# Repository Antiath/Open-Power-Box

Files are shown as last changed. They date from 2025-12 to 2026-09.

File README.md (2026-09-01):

# 🔭 Open Power Box: Heavy Duty Power Distribution System for Astrophotography Equipment
**Open Power Box** is a complete, open-source hardware and software project designed to build a robust power distribution box specifically for an **observatory-class amateur astronomy setup**. While many similar projects exist, they often target compact, portable systems; this project is built for greater capabilities. The hardware side of the project is designed following the specifications detailled below but the firmware, though preconfigured for this specific hardware, has been written to allow scalability to an arbitrary number of outputs so that one could use it as-is for his custom version of the project, with minimal adjustments to the firmware. 

**LICENSING** : The entire project is **completely open source**. The hardware files and documentation fall under the **Licence CC BY-SA 4.0**, while the drivers and the firmware are licensed under **GNU Lesser General Public License version 3 (LGPLv3)** 

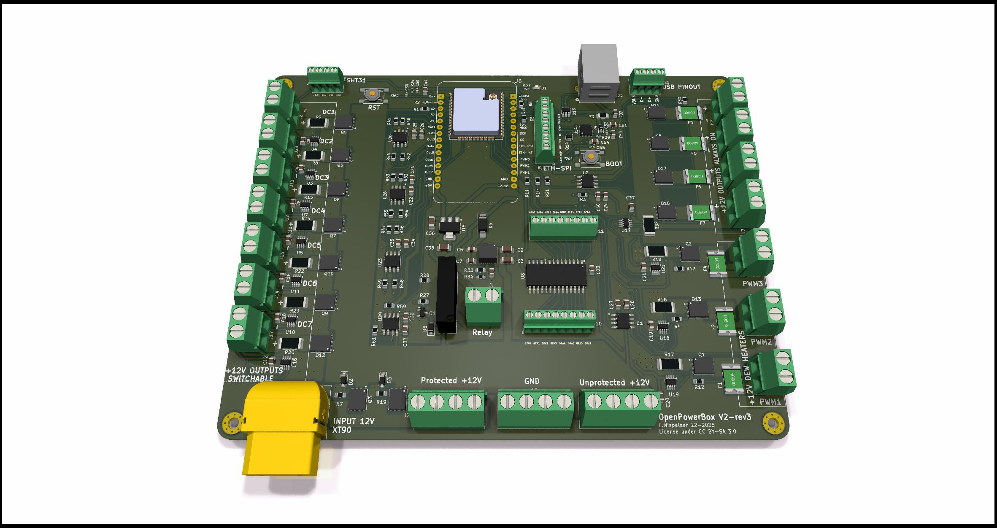
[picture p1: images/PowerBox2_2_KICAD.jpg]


## ✨ Key Features

### Power and Output Specifications
* **Input:** 12V (nominal, unregulated) DC with a **20A limit**. The polarity protection circuit can handel up to 20V without damaging it but we really recommand to stay around 12V as there is no voltage regulation on the output.
* **Switched DC Outputs:** 7 individual ON/OFF DC switches, rated at **12V/5A each**.
* **Dew Heater Outputs:** 3 outputs with low-frequency PWM control, rated at **12V/2A each**.
* **Automatic Dew Heater Control** Using a SHT31 sensor on the i2c bus, the device can regulate the power of a heater band.
* **12V Rail:** A single rail of 4 DC outputs for devices that don't need individual control, limited to **12V/5A for the whole rail**. Useful for things that stay on all the time for exemple.
* **Switchable Relay:** A relay useful for controlling a device with specific voltage requirements, max **30V-5A**.
* **Switchable USB Hub (Optional):** A 7-port switchable USB2 hub (on a second PCB). This allows for remote USB connection reset if a peripheral malfunctions, but a simple off-the-shelf hub can also be used if this feature is not needed.

### Protection and Customization
* **Configurable Software Fuses:** Most switches have a dedicated current sensor to monitor current draw and shut down the switch if a configurable limit is exceeded. These limits are stored in the EEPROM and can be modified in the clients.
* **Global Limits:** Three global current limits are also in place, one for the 7 DC switches together, one for the dew heaters together, and one for the total input current. And the total limit of 20A for the whole box (excluding the relay). These limits will shut down parts of the device in a sequence of priorities.
* **Reverse Polarity Protection:** The XT90 input connector is folowed by a reverse polarity protection circuit.
* **Reversible Logic:** Switch logic can be swapped to correct issues where the client-side toggle is reversed (ON/OFF issue).

### Connectivity and Communication
The device supports multiple communication methods, allowing a choice of OS and connection type (USB or WiFi).

| Connection Type | Operating System | Client Interface | Notes |
| :--- | :--- | :--- | :--- |
| **USB/Serial** | Windows | ASCOM Driver | The ASCOM driver provides its own minimised UI, similar to GSS or EQMOD. |
| **USB/Serial** | Linux | Indi Driver | Use the dedicated Indi driver (In development). |
| **WiFi** | Windows | Alpaca Server | Provides similar functionnality to the ASCOM USB driver but no driver installation needed if your client supports Alpaca; it finds the device on the network automatically.|
| **WiFi** | Any OS | HTTP Browser Interface | Accessible at the device's IP address on port 4040. Meant for quick device configuration only (like a router's configuration page).  |

---

## 🛠️ Project Components

The complete project includes everything you need to build and run your own power box:
* **Hardware:** Schematics, gerber files, and a Bill of Materials (BOM) list for PCB creation.
* **Enclosure:** STL files for 3D printing an enclosure.
* **Software:**
    * **Firmware:** Includes base code, serial communication, an HTTP server for a browser interface, and an ASCOM/Alpaca server.
    * **Drivers:** ASCOM Driver and Indi Driver.
 
## 🛠️ Completed build illustrations

### Standard version

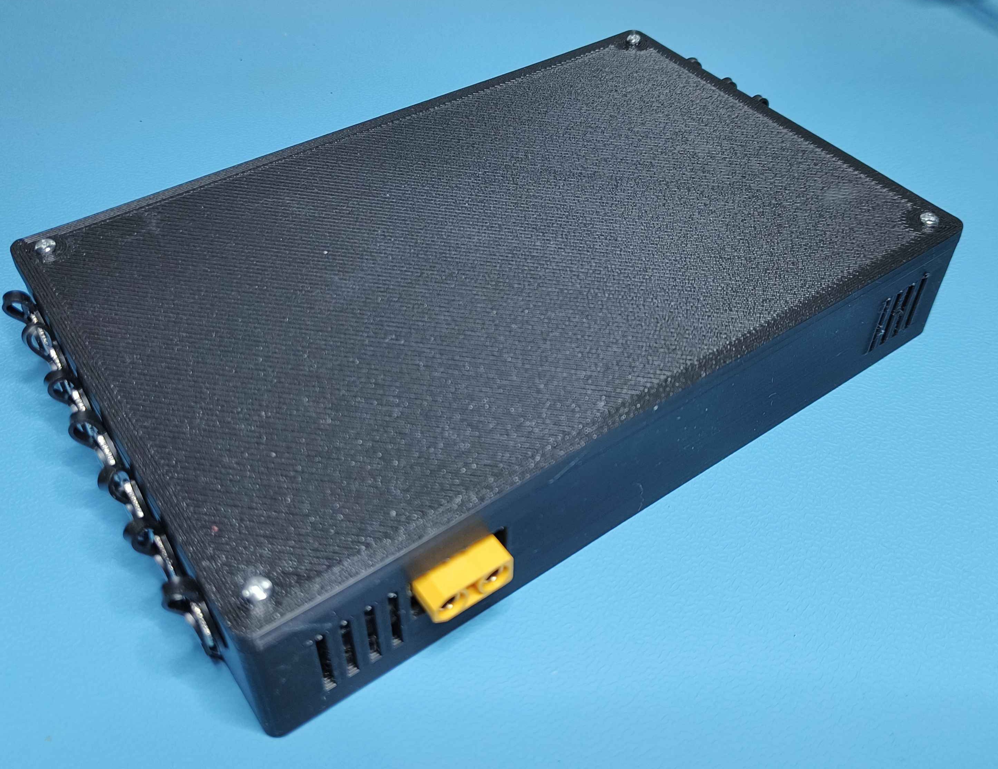
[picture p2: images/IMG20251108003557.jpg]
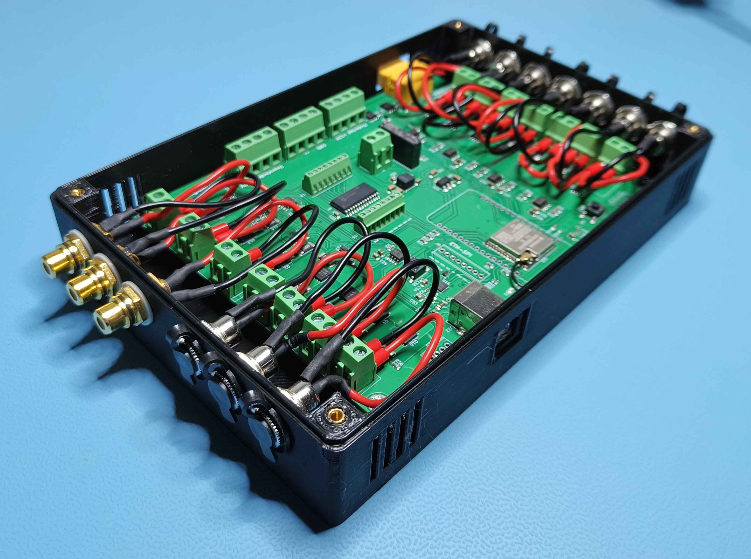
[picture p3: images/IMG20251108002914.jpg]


### USB HUB version

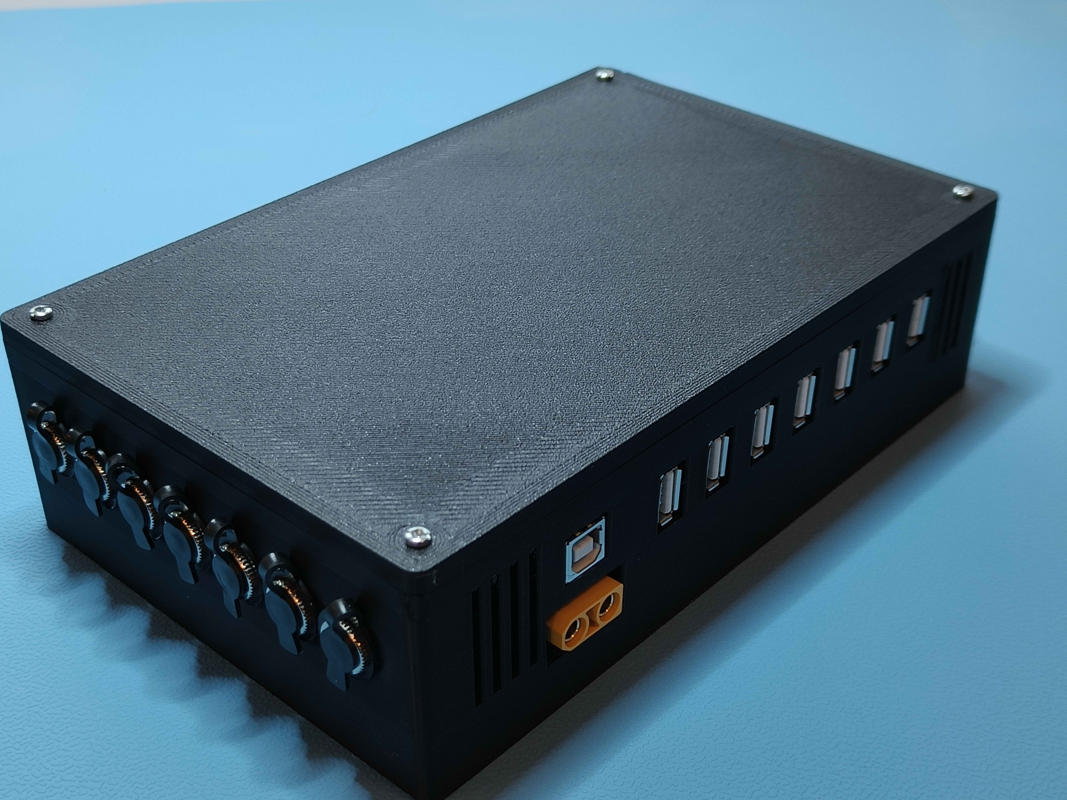
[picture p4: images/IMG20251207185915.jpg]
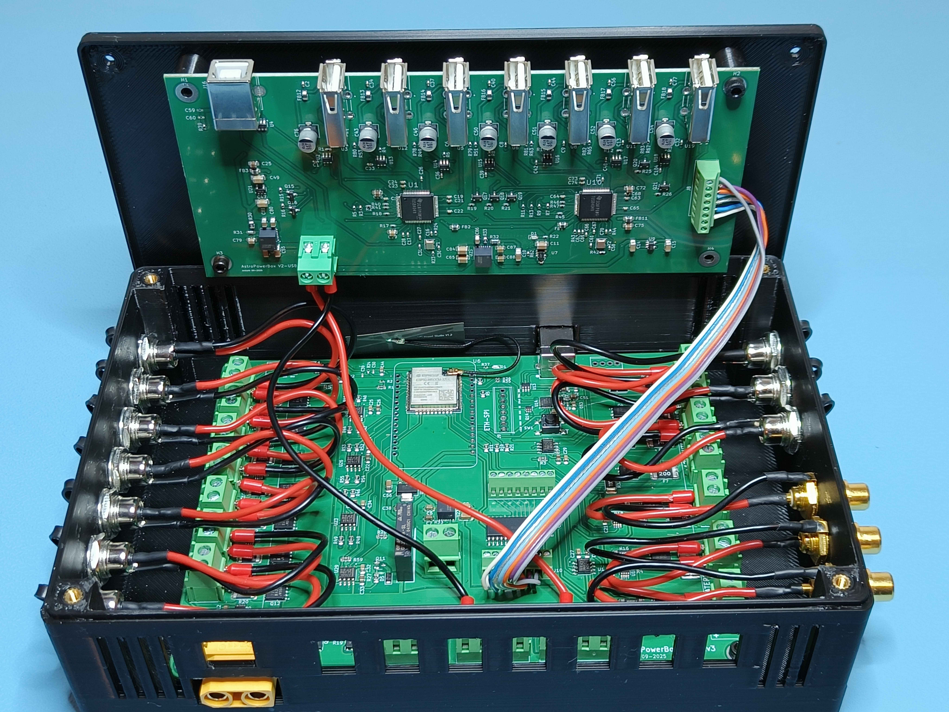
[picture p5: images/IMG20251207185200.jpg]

---

## 🚀 Getting Started

### 🔌 Flashing the firmware

Tho ways of flashing the firmware are provided. Choose the one that is the most convenient for you.

#### PlatformIO

Right now the project is configured via Visual Studio Code and PlatformIO. Open Visual studio Code, clone this repositery inside and set your workplace in the Firmware-platformIO subfolder of the repo. It should configure and download everything automatically, including the required libraries. Once everything is finished,  connect the box via USB, select the right USB Port and flash the firmware. Normally you shouldn't have anything more to do but if for some reason  the flash fails when attempting to upload,  press the BOOT button on the pcb, keep pressing and reflash again. Wait for it to finish. 

#### Arduino IDE

For the ArduinoIDE route, there is a little bit more work to be done. Download this repository somewhere. In the Firmware-ArduinoIDE subfolder, open the OpenPowerBox.ino sketch in the Arduino IDE (v2 at least). If uou dont have already done so, go into the board manager et install the dependencies for the esp32 from Espressif Systems ( not by Arduino !!!). Version 3.3.7 is known to work. Then in the library manager, install the following libraries ( I specify the version each time because more recent version may, or may not work) : 
* Adafruit BusIO (v1.17.4) by Adafruit
* Adafruit MCP23017 Arduino Library (v2.3.2) by Adafruit
* Adafruit SHT31 Library (v2.2.2) by Adafruit
* Arduinojson (v7.4.2) by Benoit Blanchon
* SerialCommand Advanced (v1.0.0) by shyd
* WebSockets (v2.7.2) by Markus Sattler
* INA219 (v0.4.2) by Rob Tillaart

Once everything is installed properly, go into Tools and select the esp32 board named " ESP32 Dev Module", select the right USB port. Also, it is not mandatory but it is still a good idea to change the partitionning of the esp32 to free up some space for the programm ( by default it would occupy 85% of the available program memory) so in Tools > Partition Scheme, select Huge APP ( 3MB No OTA, 1MB SPIFF).
Then you can try to compile. Ignore the yellow warnings, if there are no errors, flash the firmware.

#### Firmware Configuration

The default configuration of the firmware is for a power box with 7 DC outputs, 3 PWM Dew Heaters, 1 DC bank, 1 relay, 0 USB ports and Automatic Dew heating activated.
If you need any other configuration, you can edit the following lines in config.h. But be aware than any configuration other than default will make the webpage unusable.

```
const short DCOutput_Num = 7;  // Number of stable 12V outputs. 
const short PWMOutput_Num = 3; // Number of PWM controlled outputs.
const short RelayOutput_Num = 1; // Number of relay outputs.
const short OnOutput_Num = 1; // Number of always ON 12V switches (the whole bank of connectors is controlled by the same switch)
const short USBOutput_Num = 0; // Number of USB controlled outputs. Maximum is 7.
const bool Ren =true; // Falg to enable/disable the automatic power control of dew heaters. This only affects the firmware and display of the sensor, you will still have to activate automatic control in the driver.
```
For example, if you want the USB Hub version of the project, set USBOutput_Num to 7 instead of 0.
If you don't need Automatic control of the dew heaters ( meaning of you don't have a SHT31 sensor hooked up), Set Ren to false instead of true.

For the more advanced users that want to design their own pcb with an entirely different configuration, there are a few things to consider.
The main switches are DCOutput_Num and PWMOutput_Num. The DC Bank with ganged connectors behind a single transistor is specified by OnOutput_Num, and the relay by RelayOutput_Num.
If you need a different number of individual DC/PWM or USB ports, you can change DCOutput_Num, PWMOutput_Num or USBOutput_Num. Be aware that the pcb is configured for these and also that the esp32 has a limited amount of I/O. 
If you need less outputs, it's pretty easy. Just read below  in config.h to know wich pins are used by the firmware for each type of output.
If you need more outputs...(wich you really shouldn't it's already a big boy) it's possible but you would have to change the arrays that store the pin adresses of each output type and add the pins you need. 
And lastly, there can only be a maximum number of 1 for the relay and the DC Bank. The firmware doesn't allow currently for more.

To get your Open Power Box communicating with your host PC, you will need to install the appropriate drivers.

### 🔌 Windows Setup (USB/Serial)

If you are using **Windows** and connecting via **USB/Serial**, you must install the **ASCOM driver**:

1.  **Install the ASCOM Driver:** Download and install the dedicated ASCOM Driver for this project.
2.  **Connect the Device:** Connect the power box to your Windows PC via the USB/Serial interface.
3.  **Client Interface:** The driver provides a limited user interface in your preferred client (like **NINA**) with control for all the switches and display of the main measurements.
7.  **Driver UI:** When you open the COM port, in addition to the controls available in the client ,the driver will also automatically launch its own **User Interface**, minimized by default, functioning similarly to tools like GSS or EQMOD. This last UI provides the full functionnality of the device.
   
### 💻 Linux Setup (USB/Serial)

If you are using **Linux** and connecting via **USB/Serial**, you can use the provided INDI driver. It should be available through the last release of INDI but in case it isn't, you can compile from source.

1. Make sure you have a stable installation of **INDI** and **cmake**.
2. If this is not already done,  make also sure you have the right dependencies to build indi projects:
```
sudo apt install build-essential devscripts debhelper fakeroot cdbs software-properties-common cmake
sudo add-apt-repository ppa:mutlaqja/ppa
sudo apt install libindi-dev libnova-dev libz-dev libgsl-dev
```
3. Download/clone this repository, open a terminal into INDI Driver, make a new build folder and cd into it.
```
mkdir build
cd build
```
5. Inside the build folder, execute the following commands
```
cmake -DCMAKE_INSTALL_PREFIX=/usr -DCMAKE_BUILD_TYPE=Debug ../
```
You should now see the config.h and indi_opbdriver.xml files.
Stay in the Build folder and build the executable
```
make
```
and install the driver now with
```
sudo make install
```
6. In Ekos, the driver will be located in the Power category under the Generic Manufacturer and **named Open Power Box**
7. When loading the driver, you will need to paste the usb id of the device. You can find it in a terminal with
```
ls /dev/serial/by-id
```
or
```
ls -l /dev/serial/by-id
```

### 🌐 WiFi Setup

#### Setting up the WiFi credentials in the device

##### Via the USB Driver
After flashing the device with the firmware, there will be no SSID or password stored. To do that, you can use the ASCOM USB Driver. After installing it, lauch you client of choice and select the ascom driver, then your COM Port in the settings and connect. The auxiliary UI will appear. Click on the Parameter tab and below you can fill the fields for the SSID and the password. Click on the Restart button to reset the device. After a few seconds, if the device managed to connect,  the IP address displayed in the UI will be updated. The device is now ready to be used via the local network.   

##### Via Editing the Frimware
If you really don't want or can't install the usb driver, you can still store the WiFi credentials in the code before flashing it. 
Open main.cpp, find the following lines:
```
   //ssid1=""; 
   //pwd1="";
```
remove the // on both linesand add your SSID and password in the between the "", like for exemple : 
```
   ssid1="ssidwifi"; 
   pwd1="passwifi";
```
and finally Flash the device.
To get the IP address, open a Serial connection on the COM Port and push the reset button on the pcb. The IP address will be displayed during boot.
We recommand that you go into your router to reserve that IP address for the MAC address of the device.

####  Alpaca
Alpaca is a network version of the ASCOM API. It provides tools to connect to network capable devices and communicate with them in the same way you normally do with a normal USB ASCOM driver. The main difference for the user is that Alpaca only requires that you have an up to date version of ASCOM installed. It does not however requires you to any extra driver for your devices as long as the device can connect to your local network. In you preferred client, say Nina, you would go to your equpment setup page, in the switch section you would open the list of devices and OpenPowerBox should appear by itself if it is already connected to the local network. Sometimes it may take a few trys to get it to appear in the list. Select it, connect and voilà. You have basic access to the device. 

#### Browser
If you know the IP adress of the device and it is connected to the local network, you can open a page at http://ip_adress:4040/. This UI gives you access to almost all the features of the power box appart from automation. In particular, you can read every sensor available wich allows you to debug issues more easily in case of problems with a device. It also allows you to change configuration like the current limits of the software fuses, the logic polarity of the switches, tha names seen by ASCOM and wifi credentials. If the IP adress is unknown, you can get it through the USB interface.  See instructions above.

---

## 🏭 Manufacturing and Assembly Notes

### Choose your fighter : USB Hub or no USB Hub

The project proposes twho versions. The base project only has power switches ( dc and pwm) while the second version add an extra usb hub. This last one requires a second pcb dedicated to the HUB. This has been done to minimize manufacturing costs. The USB hub requires a 4 layer pcb while the power board needs only a 2 layer board. Putting everything on a single 4 layer pcb may force us to make a large and costly board. 

### Printed Circuit Board (PCB) Fabrication
* The main board is a **2-layer board** and should preferably be manufactured with a **2 oz copper thickness** to maximize the amount of copper and minimize voltage drop across the board.
* The USB hub board is a **4-layer board** and can be manufactured with a **normal 1 oz copper thickness on surface layers**. With JLC, specify the JLC04161H-3313 stackup.
  
| Layer | Material Type | Thickness |
| :---: | :---: | :---: |
| Top Layer | Copper | 0.035mm | 
| Prepreg | 3313*1 | 0.09940mm | 
| Inner Layer L2 | Copper | 0.0152mm | 
| Core | Core | 1.265mm | 
| Inner Layer L3 | Copper | 0.0152mm | 
| Prepreg | 3313*1 | 0.09940mm | 
| Bottom Layer  | Copper | 0.035mm | 

The choice of stackup affects the performance of the USB traces on the pcb or, more specificaly this stackup allows us to use really fine traces, wich simplifies the layout phase of the pcb. If you use our gerbers to make your own board, this is the stackup to use. If you choose a different stackup, you will need to re-engineer the differential pairs and redo the layout. This configuaration has been tested and achieves usb transfert speeds up to the theoritical maximum of HIGH SPEED USB2 ( 480 Mbit/s).

* Prototypes were manufactured using **JLC PCB**. If you choose the same manufacturer and encounter out-of-stock parts not easily replaced by an equivalent, you can request that JLC source those specific parts on the global market for use during manufacturing.

### Wiring
* If you are using the provided **3D printable case**, the terminal blocks on the PCB should be oriented **inward** to facilitate easier wiring to the external connectors.
* The connectors you will choose to use need to be rated for the currents you want. Typycal 12v barrel jacks and RCA jacks are not generally made to support large currents so you should be careful when selecting them. The ones used for the building of the test units were found on Amazon and may not be available anymore when you read this. iF you choose other connectors and want to use our 3dprinted case, make sure to correct the hole diamater if necessary.
* The XT90 innput connector we use accepts a gauge of 10 AWG wich should be suitable for 20-30A over 1 or 2m. Flexible multistranded wire should be used here in order to avoid resistance when moving the telescope around as the powerbox would be typically put on top of the setup and its power cable would laying down to you power supply.
* Always size the other cables appropriatly. If you expect to use the full 5A of an output, not only the gauge should be checked but also every intermediary connector, if possible, as they are very likely to not make good enough contact for this kind of stress.
* Terminate your internal wires with ferrules when connecting to a terminal block.
* If you need the SHT31 sensor for the automatic Dew heater deature, there is a row of of 4 holes in a corner of the pcb named SHT31. Solder a 4 slots 2.54mm terminal block or just solder your wires directly. The silkscreen indicates wich pad does what.
* The switching of the usb ports of the hub are handled by the I/O port extender (MCP23017) of the main board. Wiring between the two boards:
  
| Main board | USB Hub board |
| :---: | :---: |
| Connector J10 | Connector J8 | 
| GPA0 | USB-S1 |
| GPA1 | USB-S2 |
| GPA2 | USB-S3 |
| GPA3 | USB-S4 |
| GPA4 | USB-S5 |
| GPA5 | USB-S6 |
| GPA6 | USB-S7 |
  
### Extra component sourcing (if still available at the time of reading):
   * 5.5mm x 2.1mm female barrel jacks from manufacturer RUNCCI-YUN: https://www.amazon.fr/dp/B09TVDDWN2?ref=ppx_yo2ov_dt_b_fed_asin_title
   * RCA female jacks from RUNCCI-YUN: https://www.amazon.fr/dp/B09TPL4TV5?ref=ppx_yo2ov_dt_b_fed_asin_title
   * XT90 connector https://www.amazon.fr/dp/B0CF85B2LY?ref=ppx_yo2ov_dt_b_fed_asin_title&th=1
   * Suitable power supply : Mean well LRS-350-12 wich is a 350W PSU ( or the LRS-450-12 if you can afford it) https://www.meanwell.com/webapp/product/search.aspx?prod=LRS-350 

---

## ⚙️ ASCOM Switch Class Overview

The power box is designed around the **ASCOM Switch class**, which is tailored for peripherals like power boxes and handles On/Off switches, Dew Heaters, and sensors.

In the ASCOM world, these entities are all referred to as a **"switch"**:

* **ON/OFF Switches:** Self-explanatory.
* **Dew Heaters:** Referred to as "**analog**" switches with an infinite range of values instead of just two.
* **Sensors:** Considered "**read-only**" switches.

Clients determine the switch type by querying the `CanWrite`, `Min`, `Max` and `Step` properties. The state of all switches is stored in a large array, with an index defining the order they are read by the client.

### Example Switch Array Structure

| Index | Switch Name | Can Write | Min-Max | Step |
| :---: | :---: | :---: | :---: | :---: |
| 0 | dc1 | Yes | 0-1 | 1 |
| 1 | dc2 | Yes | 0-1 | 1 |
| 2 | pwm | Yes | 0-100 | 10 |
| 3 | sensor | No | - | - |

### Full Switch array

Base Version:

| Switch | DC1 | DC2 | DC3 | DC4 | DC5 | DC6 | DC7 | PWM1 | PWM2 | PWM3 | Ren1 | Ren2 | Ren3 | DC Rail | Relay | Input V | Total A | Total A DC | Total A PWM | DC1_V | DC1_A | DC2_V | DC2_A | DC3_V | DC3_A | DC4_V | DC4_A | DC5_V | DC5_A | DC6_V | DC6_A | DC7_V | DC7_A | PWM1_V | PWM1_A | PWM2_V | PWM2_A | PWM3_V | PWM3_A | DC Rail_V | DC Rail_A | Temp | Hum | Dew_point |
|---|---|---|---|---|---|---|---|---|---|---|---|---|---|---|---|---|---|---|---|---|---|---|---|---|---|---|---|---|---|---|---|---|---|---|---|---|---|---|---|---|---|---|---|---|
| index | 0 | 1 | 2 | 3 | 4 | 5 | 6 | 7 | 8 | 9 | 10 | 11 | 12 | 13 | 14 | 15 | 16 | 17 | 18 | 19 | 20 | 21 | 22 | 23 | 24 | 25 | 26 | 27 | 28 | 29 | 30 | 31 | 32 | 33 | 34 | 35 | 36 | 37 | 38 | 39 | 40 | 41 | 42 | 43 |

USB HUB Version:

| Switch | DC1 | DC2 | DC3 | DC4 | DC5 | DC6 | DC7 | PWM1 | PWM2 | PWM3 | Ren1 | Ren2 | Ren3 | DC Rail | Relay | USB1 | USB2 | USB3 | USB4 | USB5 | USB6 | USB7 | Input V | Total A | Total A DC | Total A PWM | DC1_V | DC1_A | DC2_V | DC2_A | DC3_V | DC3_A | DC4_V | DC4_A | DC5_V | DC5_A | DC6_V | DC6_A | DC7_V | DC7_A | PWM1_V | PWM1_A | PWM2_V | PWM2_A | PWM3_V | PWM3_A | DC Rail_V | DC Rail_A | Temp | Hum | Dew_point |
|---|---|---|---|---|---|---|---|---|---|---|---|---|---|---|---|---|---|---|---|---|---|---|---|---|---|---|---|---|---|---|---|---|---|---|---|---|---|---|---|---|---|---|---|---|---|---|---|---|---|---|---|
| index | 0 | 1 | 2 | 3 | 4 | 5 | 6 | 7 | 8 | 9 | 10 | 11 | 12 | 13 | 14 | 15 | 16 | 17 | 18 | 19 | 20 | 21 | 22 | 23 | 24 | 25 | 26 | 27 | 28 | 29 | 30 | 31 | 32 | 33 | 34 | 35 | 36 | 37 | 38 | 39 | 40 | 41 | 42 | 43 | 44 | 45 | 46 | 47 | 48 | 49 | 50 |

---

## 💬 Serial Communication Protocol
If you choose to use USB to interact with the device, the firmware communicates via serial commands over the COM port. While the webserver is regularly updated, there is no data sent automatically through the serial port, the driver has to poll the device. This means that, for now, the general behavior of the COM port is synchronous.
Each command sent to the device will trigger a response even if no data is necesseraily expected back. For example, if you send the command to change the sate of a switch, the device will execute the command and then send the changed state back as an answer to acknowlege the action.  Also, the formatting of the commands sent to the device is different than the formatting of the reponse. This is intentionnal and allows for easier debugging when sniffing the com port. 

### Command Format (from Host to Device)

Commands use a simple letter and one or two parameters:

* **To Get a Value:** `# <command> <index>`
    * *Example (Get value of the first DC switch - index 0):* `# G 0`
* **To Set a Value:** `# <command> <index> <value>`
    * *Example (Set PWM index 2 to 55):* `# S 2 55`

* The response starts with `#`.
* A space separates the command letter from the index and the index from the value ( if one is required).
* If no index is needed, `0` is included by default.
* No character to terminate other than a newline and carriage return.

### Response Format

Every command  from the client triggers a response:

* **Responding to a Get command:** `#<command><index>:<value>;`
    * *Example (Get value of the first DC switch - index 0, the value is 1):* `#G0:1;`

* The response starts with `#` and is terminated with `;` (plus newline and carriage return).
* A `:` character separates the index from the value.
* No spaces are included.

### ASCOM Compliant Commands

| Method | Command | Response Format | Type [Range] | Description |
| :--- | :--- | :--- | :--- | :--- |
| **Get switch value** | `# G <index>` | `#G<index>:<value>;` | Dc: boo[0-1], PWM: int [0-100], Sensor: float | Get the current state/value of a switch |
| **Set switch value** | `# S <index> <value>` | `#G<index>:<value>;` | Dc: boo[0-1], PWM: int [0-100] | Set the state/value of a switch |
| **Can Write** | `# W <index>` | `#W<index>:<value>;` | boo[0-1] | Tells if the switch is writable or not |
| **Maximum** | `# M <index>` | `#M<index>:<value>;` | Dc: int[1], PWM: int [100] | Gives the maximum writable value |
| **Minimum** | `# m <index>` | `#m<index>:<value>;` | Dc: int[0], PWM: int [0] | Gives the minimum writable value |
| **Get Switch Name** | `# n <index>` | `#n<index>:<value>;` | String | Get the name of a switch |
| **Set Switch Name** | `# N <index> <value>` | `#n<index>:<value>;` | String | Set the name of a switch |
| **Max switch (Total Count)** | `# X 0` | `#x0:<value>;` | Int | Total number of switches (length of the switch array) |
| **Get Switch Description** | `# D <index>` | `#D<index>:<value>;` | String | Get the description of a switch |

### Custom Commands

This project includes extra custom commands for device-specific features:

| Method | Command | Response Format | Type [Range] | Description |
| :--- | :--- | :--- | :--- | :--- |
| **Set Visible** | `# Y <index> <value>` | `#y<index>:<value>;` | boo[0-1] | Set the flag for driver display (show/hide switch) |
| **Get Visible** | `# y <index>` | `#y<index>:<value>;` | boo[0-1] | Get the display flag |
| **Set Reverse** | `# R <index> <value>` | `#r<index>:<value>;` | boo[0-1] | Set the polarity of a switch |
| **Get Reverse** | `# r <index> <value>` | `#r<index>:<value>;` | boo[0-1] | Get the polarity of a switch |
| **Get Limit** | `# l <index>` | `#l<index>:<value>;` | Int | Get the current limit of a switch |
| **Set Limit** | `# L <index>` | `#l<index>:<value>;` | Int | Set the current limit of a switch |
| **Get local IP** | `# I 0` | `#I0:<value>;` | String | Get the IP Address of the device |
| **Set WiFi SSID** | `# F 0 <ssid>` | `#f0:<value>;` | String | Set the SSID of the WiFi AP |
| **Get WiFi SSID** | `# f 0` | `#f0:<value>;` | String | Get the SSID of the WiFi AP |
| **Set WiFi PASSWORD** | `# H 0 <password>` | `--------` | String | Set the password of the WiFi AP |
| **Restart ESP32** | `# p 0` | `--------` | - | Restart the device |
| **Get Last Error** | `# e 0` | `#e0:<value>;` | String | Get the last error message raised by the device |

---

## 💡 Extra
Space is included on the PCB for future expansion, although the code for these features is not yet implemented:
* **Ethernet Module:** Provisions for an Ethernet module via SPI bus (not implemented in code).

## DISCLAIMER
1) This project in its entirity is provided as is without any guarranty of functionnality or safety. In case of issues with the hardware or the software we may or may not provide technical support.
2) This project has been conceived from the start with the objective to limit electrical hazards as much as reasonnably possible. It includes multiple safety measures such as hardware fuses, software fuses and polarity protection of the main input. The pcb we made has also been stress tested to make sure it doesn't catch fire when pushing it to the higher currents we rated the project for.  Nonetheless there is always a risk of something going wrong with high current devices. **We decline any responsability in case of any accident occuring during the build AND the use of the device.**
When building this project, we HIGHLY recommend to :
   * make sure you have the required skills and knowledge to build/modify/manipulate electronic devices such as this one. 
   * oversize your cables whenever possible.
   * Make sure your connectors are able to support the current you need. This is easier said than done but at least keep the idea in mind when shopping. 
3) Even with all precautions taken, there will be a significant voltage drop when drawing multiple amps. If your peripheral is sensitive to voltage drops (like QHY cameras) and raising the voltage of the supply to compensate is not a safe option,  than we recommand to power the the device separatly. We measured a typical internal resistance of 10 mOhms per output (through all the device) wich will cause a typical 0.1V to 0.15V drop when pushing the powerbox to its limits. **If you still see significantly more voltage drop than this, the culprit is more than likely your cabling or a connector.**

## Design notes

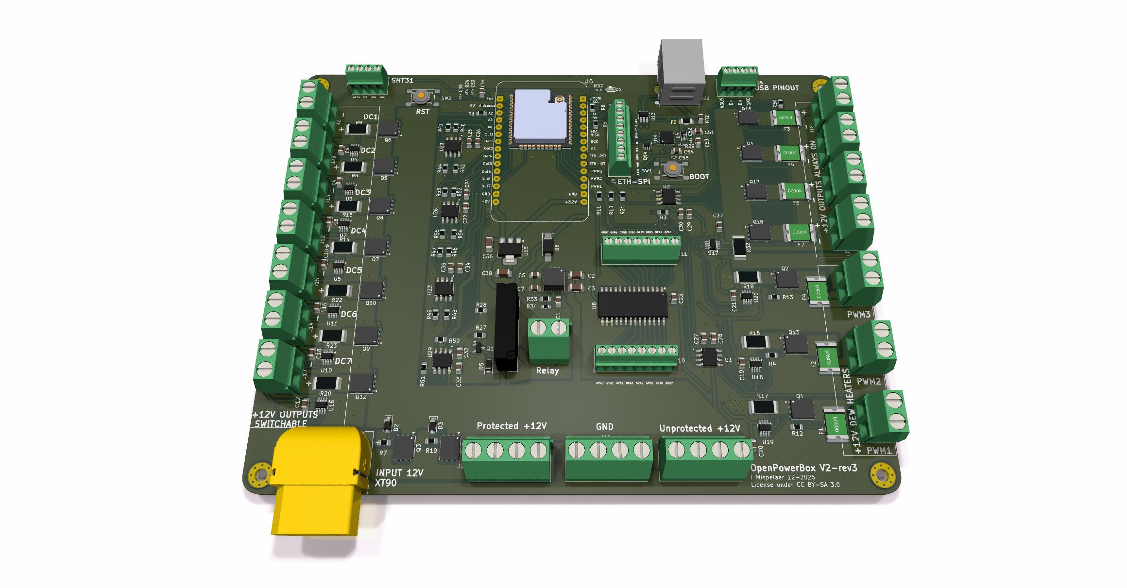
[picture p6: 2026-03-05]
PowerBox2_2_KICAD.jpg

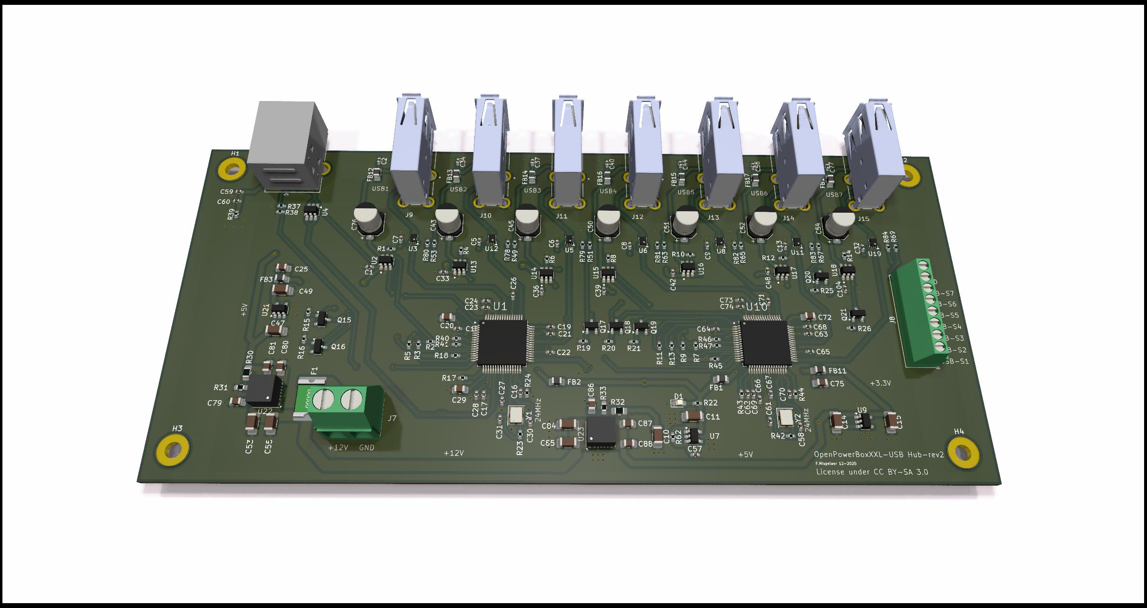
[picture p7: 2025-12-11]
PCB Files/USB HUB Board/USB2hub.jpg

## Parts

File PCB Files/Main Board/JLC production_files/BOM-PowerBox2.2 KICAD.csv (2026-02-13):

Comment | Designator | Footprint | LCSC
10K | R33 | R_0805_2012Metric_Pad1.20x1.40mm_HandSolder | C110775
47u | C5,C7 | C_0805_2012Metric_Pad1.18x1.45mm_HandSolder | C124129
22u | C38,C56 | C_1206_3216Metric_Pad1.33x1.80mm_HandSolder | C12891
UCC27424 | U1,U2,U20,U23,U26,U29 | SOIC127P599X175-8N | C138519
Si7145DP | Q10,Q12,Q15,Q16,Q17,Q18,Q3,Q4,Q5,Q6,Q7,Q8,Q9 | PowerPAK_SO-8_Single | C144873
100k | R19,R7 | R_0805_2012Metric_Pad1.20x1.40mm_HandSolder | C149504
Zener 8V | D2,D3 | D_SOD-123 | C151594
100n | C39,C50,C52,C55 | C_0402_1005Metric_Pad0.74x0.62mm_HandSolder | C1525
D | D5 | D_SOD-123F | C169542
10k | R10,R11,R21,R28,R3,R40,R41,R46,R47,R52,R53,R59 | R_0805_2012Metric_Pad1.20x1.40mm_HandSolder | C17414
470 | R12,R13,R27,R30,R4,R42,R44,R48,R49,R54,R55,R61 | R_0805_2012Metric_Pad1.20x1.40mm_HandSolder | C17710
4u7 | C53 | C_0805_2012Metric_Pad1.18x1.45mm_HandSolder | C1779
2N7002H | Q19 | SOT-23 | C22446827
TLV1117LV-3.3 | U15 | SOT-223-3_TabPin2 | C23984
1K | R37 | R_0402_1005Metric_Pad0.72x0.64mm_HandSolder | C242161
SW_SPST | SW1,SW2 | SW_Push_1P1T_NO_6x6mm_H9.5mm | C255812
3.3k | R5,R6 | R_0805_2012Metric_Pad1.20x1.40mm_HandSolder | C26010
10K | R24,R29 | R_0402_1005Metric_Pad0.72x0.64mm_HandSolder | C2759535
1uF | C1,C23 | C_0805_2012Metric_Pad1.18x1.45mm_HandSolder | C28323
1200 0.1% | R2 | R_0402_1005Metric_Pad0.72x0.64mm_HandSolder | C2838713
TPSM53603RDA | U22 | Texas_B3QFN-14-1EP_5x5.5mm_P0.65mm_ThermalVia | C2860943
1m 1% | R14,R15,R16,R17,R18,R20,R22,R23,R32,R8,R9 | R_2512_6332Metric_Pad1.40x3.35mm_HandSolder | C2903470
Screw_Terminal_01x04 | J16,J21,J8 | TerminalBlock_Phoenix_MKDS-1,5-4-5.08_1x04_P5.08mm_Horizontal | C2915641
XT90PW-F | J24 | AMASS_XT90PW-F | C3040690
10uF | C2,C3 | C_1206_3216Metric_Pad1.33x1.80mm_HandSolder | C363964
G6DN-1A-SL DC12 | K1 | G6DN-1A-L | C397210
22R | R35,R36 | R_0402_1005Metric_Pad0.72x0.64mm_HandSolder | C417075
10µF | C22,C26,C28,C30,C33,C35 | C_0805_2012Metric_Pad1.18x1.45mm_HandSolder | C440198
SiR182DP | Q1,Q13,Q2 | PowerPAK_SO-8_Single | C467943
CP2104 | U14 | QFN-24-1EP_4x4mm_P0.5mm_EP2.6x2.6mm | C47742
Polyfuse 1A | F9 | Fuse_1206_3216Metric_Pad1.42x1.75mm_HandSolder | C6165191
UMH3N | Q14 | SOT-363_SC-70-6 | C62892
MCP23017T-E_SO | U8 | SOIC127P1030X265-28N | C629440
2.49K | R34 | R_0603_1608Metric_Pad0.98x0.95mm_HandSolder | C705842
18000 0.1% | R1 | R_0805_2012Metric_Pad1.20x1.40mm_HandSolder | C706223
Screw_Terminal_01x02 | J1,J12,J13,J14,J15,J17,J18,J19,J2,J20,J23,J3,J4,J5,J7 | TerminalBlock_bornier-2_P5.08mm | C709041
BHFUSE BSMD2920-300-30V | F1,F2,F4 | Fuse_2920_7451Metric_Pad2.10x5.45mm_HandSolder | C7190311
USB_B | J22 | CONN4_10-BRW_XNP | C720549
D_Schottky | D4 | D_SOD-323_HandSoldering | C7380001
USBLC6-2P6 | U13 | SOT-23-6_Handsoldering | C7519
100nF | C10,C12,C16,C18,C19,C20,C21,C24,C25,C27,C29,C32,C34,C37,C4,C6,C8 | C_0805_2012Metric_Pad1.18x1.45mm_HandSolder | C77082
BLM21PG221 | FB2 | L_0805_2012Metric_Pad1.15x1.40mm_HandSolder | C85840
D_Schottky-3A | D6 | D_SMA_Handsoldering | C8678
INA219AxDCN | U10,U11,U16,U17,U18,U19,U21,U3,U4,U5,U7 | SOT-23-8_Handsoldering | C87469
BHFUSE BSMD2920-200-33V | F3,F5,F6,F7 | Fuse_2920_7451Metric_Pad2.10x5.45mm_HandSolder | C910843
GREEN | D1 | LED_0603_1608Metric_Pad1.05x0.95mm_HandSolder | C965804
22u | C44,C51,C54 | C_0805_2012Metric_Pad1.18x1.45mm_HandSolder | C98190

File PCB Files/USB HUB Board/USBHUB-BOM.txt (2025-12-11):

Reference	Value	Package	LCSC	MFR Part	Manufacturer	Qty	Datasheet	DNP
C14,C15,C29,C47,C49	1u	-- mixed values --	-- mixed values --	-- mixed values --	Samsung Electro-Mechanics	5	~	
R39,R49,R51,R53,R63,R65,R67,R69,R78,R79,R80,R81,R82,R83,R84	0	0402	C17168	0402WGF0000TCE	UNI-ROYAL(Uniroyal Elec)	15	~	
R22,R62	1K	0402	C11702	0402WGF1001TCE	UNI-ROYAL(Uniroyal Elec)	2	~	
R23,R42	1M	0402	C26083	0402WGF1004TCE	UNI-ROYAL(Uniroyal Elec)	2	~	
R1,R4,R6,R8,R10,R12,R14	30k 1%	0402	C25776	0402WGF3002TCE	UNI-ROYAL(Uniroyal Elec)	7	~	
R17,R18,R40,R41,R43,R45,R46,R47	4.7k	0402	C25900	0402WGF4701TCE	UNI-ROYAL(Uniroyal Elec)	8	~	
R24,R44	9.53k	0402	C96273	0402WGF9531TCE	UNI-ROYAL(Uniroyal Elec)	2	~	
F1	Polyfuse	2920	C207091	2920L500/16MR	LittelFuse	1	~	
FB1,FB2,FB3,FB11,FB12,FB13,FB14,FB15,FB16,FB17,FB18	BLM21PG221	0805	C85840	BLM21PG221SN1D	Murata Electronics	11	~	
Q15,Q16,Q17,Q18,Q19,Q20,Q21	BSS138	SOT-23	C40912	BSS138-7-F	Diodes Incorporated	7	https://jlcpcb.com/api/file/downloadByFileSystemAccessId/8560092272794116096	
C1,C2,C5,C6,C7,C8,C9,C13,C16,C17,C18,C19,C21,C22,C23,C24,C26,C27,C28,C32,C33,C34,C36,C37,C39,C40,C42,C44,C48,C56,C57,C63,C64,C65,C66,C67,C68,C69,C70,C71,C73,C74,C77,C104	100n	0402	C1525	CL05B104KO5NNNC	Samsung Electro-Mechanics	44	~	
C20,C25,C72,C75	10u	0805	C15850	CL21A106KAYNNNE	Samsung Electro-Mechanics	4	~	
C79,C86	1uF	0805	C28323	CL21B105KBFNNNE	Samsung Electro-Mechanics	2	~	
C10,C11	22u	1206	C12891	CL31A226KAHNNNE	Samsung Electro-Mechanics	2	~	
R2,R3,R5,R7,R9,R11,R13,R15,R16,R19,R20,R21,R25,R26	10k	0402	C71617	CRCW040210K0FKED	Vishay Intertech	14	~	
R38	10k 1%	0402	C71617	CRCW040210K0FKED	Vishay Intertech	1	~	
R37	90.9k 1%	0402	C2076677	CRCW040290K9FKED	Vishay Intertech	1	~	
J8	Conn_01x08	Plugin,P=2.54mm	C918126	DB125-2.54-8P-GN-S	DORABO	1	~	
C43,C45,C50,C51,C52,C54,C76	150uF	SMD,D5xL5.8mm	C336797	EEEFT1A151AR	PANASONIC	7	~	
C30,C31,C58,C61	18pF	0402	C5137554	FCC0402N180J500AT	FOJAN	4	~	
C62	2.2u	0402	C385032	GRM155R61E225KE11D	Murata Electronics	1	~	
C80,C81,C87,C88	47u	0805	C124129	GRM21BR61A476ME15L	Murata Electronics	4	~	
C53,C55,C84,C85	10uF	1206	C363964	GRT31CR61H106ME01L	Murata Electronics	4	~	
J7	Conn_01x02	P=5.08mm	C709041	JL500-50802G01	JILN	1	~	
R31,R33	2.49K 0.1%	0603	C705842	RT0603BRE072K49L	YAGEO	2	~	
R30,R32	10K 0.1%	0805	C110775	RT0805BRD0710KL	YAGEO	2	~	
U9,U21	TLV73311	SOT-23-5	C2865431	TLV73311PDBVR	Texas Instruments	2	https://www.ti.com/lit/ds/symlink/tlv733p-q1.pdf?ts=1765394558367	
U7	TLV75733	SOT-23-5	C485517	TLV75733PDBVR	Texas Instruments	1	https://www.ti.com/lit/ds/symlink/tlv757p.pdf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	
U2,U13,U14,U15,U16,U17,U18	TPS25221DBVR	SOT-23-6 Texas Instruments	C470965	TPS25221DBVR	Texas Instruments	7	https://www.ti.com/lit/ds/symlink/tps25221.pdf?ts=1765380771285	
U22,U23	TPSM53603RDA	B3QFN-15(5x5.5)	C2860943	TPSM53603RDAR	Texas Instruments	2	https://www.ti.com/lit/ds/symlink/tpsm53603.pdf	
U3,U5,U6,U8,U11,U12,U19	TS3USB30ERSWR	UQFN-10(1.4x1.8)	C73880	TS3USB30ERSWR	Texas Instruments	7	https://www.ti.com/lit/ds/symlink/ts3usb30.pdf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	
U1,U10	TUSB4041IPAP	HTQFP-64 Texas Instruments	C192089	TUSB4041IPAPR	Texas Instruments	2	https://www.ti.com/lit/ds/symlink/tusb4041i.pdf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	
Y1,Y2	24MHz	SMD3225-4P	C362340	TXM24M0004322FBCDO00T	Yajingxin	2	https://jlcpcb.com/api/file/downloadByFileSystemAccessId/8588920056722173952	
J9,J10,J11,J12,J13,J14,J15	USB_A	USB-A-Vertical	C26235	USB-AF侧插铜	Jing Extension of the Electronic Co.	7	 ~	
J16	USB_B	USB-B-Vertical	C720549	USB-B10-BRW	XUNPU	1	 ~	
U4	USBLC6-2P6	SOT-23-6L	C7519	USBLC6-2SC6	STMicroelectronics	1	https://www.st.com/resource/en/datasheet/usblc6-2.pdf	
D1	GREEN	0603	C965804	XL-1608UGC-04	XINGLIGHT	1	~

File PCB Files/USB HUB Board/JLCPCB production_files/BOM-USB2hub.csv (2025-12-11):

Comment | Designator | Footprint | LCSC
10K 0.1% | R30,R32 | R_0805_2012Metric_Pad1.20x1.40mm_HandSolder | C110775
1K | R22,R62 | R_0402_1005Metric_Pad0.72x0.64mm_HandSolder | C11702
47u | C80,C81,C87,C88 | C_0805_2012Metric_Pad1.18x1.45mm_HandSolder | C124129
22u | C10,C11 | C_1206_3216Metric_Pad1.33x1.80mm_HandSolder | C12891
100n | C1,C104,C13,C16,C17,C18,C19,C2,C21,C22,C23,C24,C26,C27,C28,C32,C33,C34,C36,C37,C39,C40,C42,C44,C48,C5,C56,C57,C6,C63,C64,C65,C66,C67,C68,C69,C7,C70,C71,C73,C74,C77,C8,C9 | C_0402_1005Metric_Pad0.74x0.62mm_HandSolder | C1525
10u | C20,C25,C72,C75 | C_0805_2012Metric_Pad1.18x1.45mm_HandSolder | C15850
0 | R39,R49,R51,R53,R63,R65,R67,R69,R78,R79,R80,R81,R82,R83,R84 | R_0402_1005Metric_Pad0.72x0.64mm_HandSolder | C17168
1u | C14,C15,C47,C49 | C_1206_3216Metric_Pad1.33x1.80mm_HandSolder | C1848
TUSB4041IPAP | U1,U10 | IC_TFP410PAP | C192089
Polyfuse | F1 | Fuse_2920_7451Metric_Pad2.10x5.45mm_HandSolder | C207091
90.9k 1% | R37 | R_0402_1005Metric_Pad0.72x0.64mm_HandSolder | C2076677
30k 1% | R1,R10,R12,R14,R4,R6,R8 | R_0402_1005Metric_Pad0.72x0.64mm_HandSolder | C25776
4.7k | R17,R18,R40,R41,R43,R45,R46,R47 | R_0402_1005Metric_Pad0.72x0.64mm_HandSolder | C25900
1M | R23,R42 | R_0402_1005Metric_Pad0.72x0.64mm_HandSolder | C26083
USB_A | J10,J11,J12,J13,J14,J15,J9 | JING_C26235 | C26235
1u | C29,C79,C86 | C_0805_2012Metric_Pad1.18x1.45mm_HandSolder | C28323
TPSM53603RDA | U22,U23 | Texas_B3QFN-14-1EP_5x5.5mm_P0.65mm_ThermalVia | C2860943
TLV73311 | U21,U9 | SOT-23-5 | C2865431
150uF | C43,C45,C50,C51,C52,C54,C76 | CP_Elec_5x5.8 | C336797
24MHz | Y1,Y2 | Crystal_SMD_3225-4Pin_3.2x2.5mm | C362340
10uF | C53,C55,C84,C85 | C_1206_3216Metric_Pad1.33x1.80mm_HandSolder | C363964
2.2u | C62 | C_0402_1005Metric_Pad0.74x0.62mm_HandSolder | C385032
BSS138 | Q15,Q16,Q17,Q18,Q19,Q20,Q21 | SOT-23 | C40912
TPS25221DBVR | U13,U14,U15,U16,U17,U18,U2 | SOT95P280X145-6N | C470965
TLV75733 | U7 | SOT-23-5 | C485517
18pF | C30,C31,C58,C61 | C_0402_1005Metric_Pad0.74x0.62mm_HandSolder | C5137554
2.49K 0.1% | R31,R33 | R_0603_1608Metric_Pad0.98x0.95mm_HandSolder | C705842
Conn_01x02 | J7 | TerminalBlock_bornier-2_P5.08mm | C709041
10k | R11,R13,R15,R16,R19,R2,R20,R21,R25,R26,R3,R38,R5,R7,R9 | R_0402_1005Metric_Pad0.72x0.64mm_HandSolder | C71617
USB_B | J16 | USB_B_OST_USB-B1HSxx_Horizontal | C720549
TS3USB30ERSWR | U11,U12,U19,U3,U5,U6,U8 | UQFN-10_1.4x1.8mm_P0.4mm | C73880
USBLC6-2P6 | U4 | SOT-23-6_Handsoldering | C7519
BLM21PG221 | FB1,FB11,FB12,FB13,FB14,FB15,FB16,FB17,FB18,FB2,FB3 | L_0805_2012Metric_Pad1.15x1.40mm_HandSolder | C85840
Conn_01x08 | J8 | TerminalBlock_TE_282834-8_1x08_P2.54mm_Horizontal | C918126
9.53k | R24,R44 | R_0402_1005Metric_Pad0.72x0.64mm_HandSolder | C96273
GREEN | D1 | LED_0603_1608Metric_Pad1.05x0.95mm_HandSolder | C965804

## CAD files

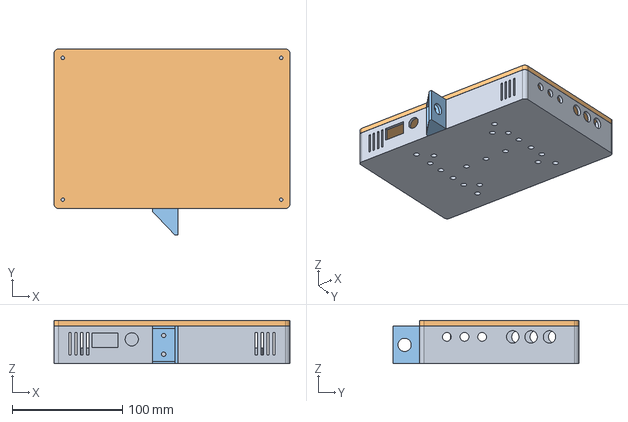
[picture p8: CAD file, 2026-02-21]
3D Files/Base version/OPB_enclosure.step
214.1 x 168.6 x 39.2 mm

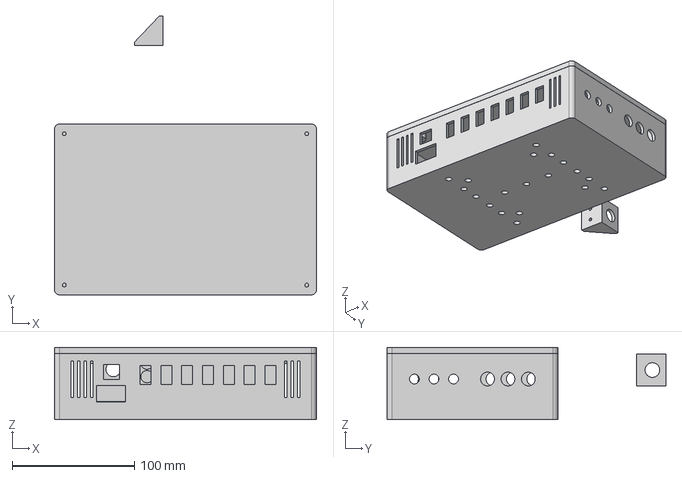
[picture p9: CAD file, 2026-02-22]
3D Files/USB HUB version/OPB_enclosure_USB.step
214.1 x 227.8 x 59.2 mm

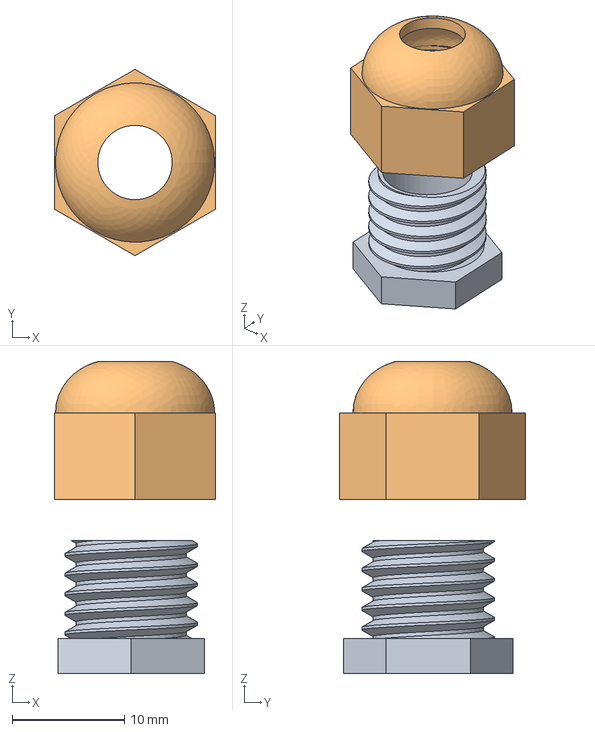
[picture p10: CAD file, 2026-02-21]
3D Files/Base version/Gland_PG7_M12.step
14.4 x 16.6 x 27.8 mm

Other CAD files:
3D Files/Base version/Gland_PG7_M12.f3d
3D Files/Base version/OPB_enclosure.f3d
3D Files/USB HUB version/Gland_PG7_M12.f3d
3D Files/USB HUB version/OPB_enclosure_USB.f3z

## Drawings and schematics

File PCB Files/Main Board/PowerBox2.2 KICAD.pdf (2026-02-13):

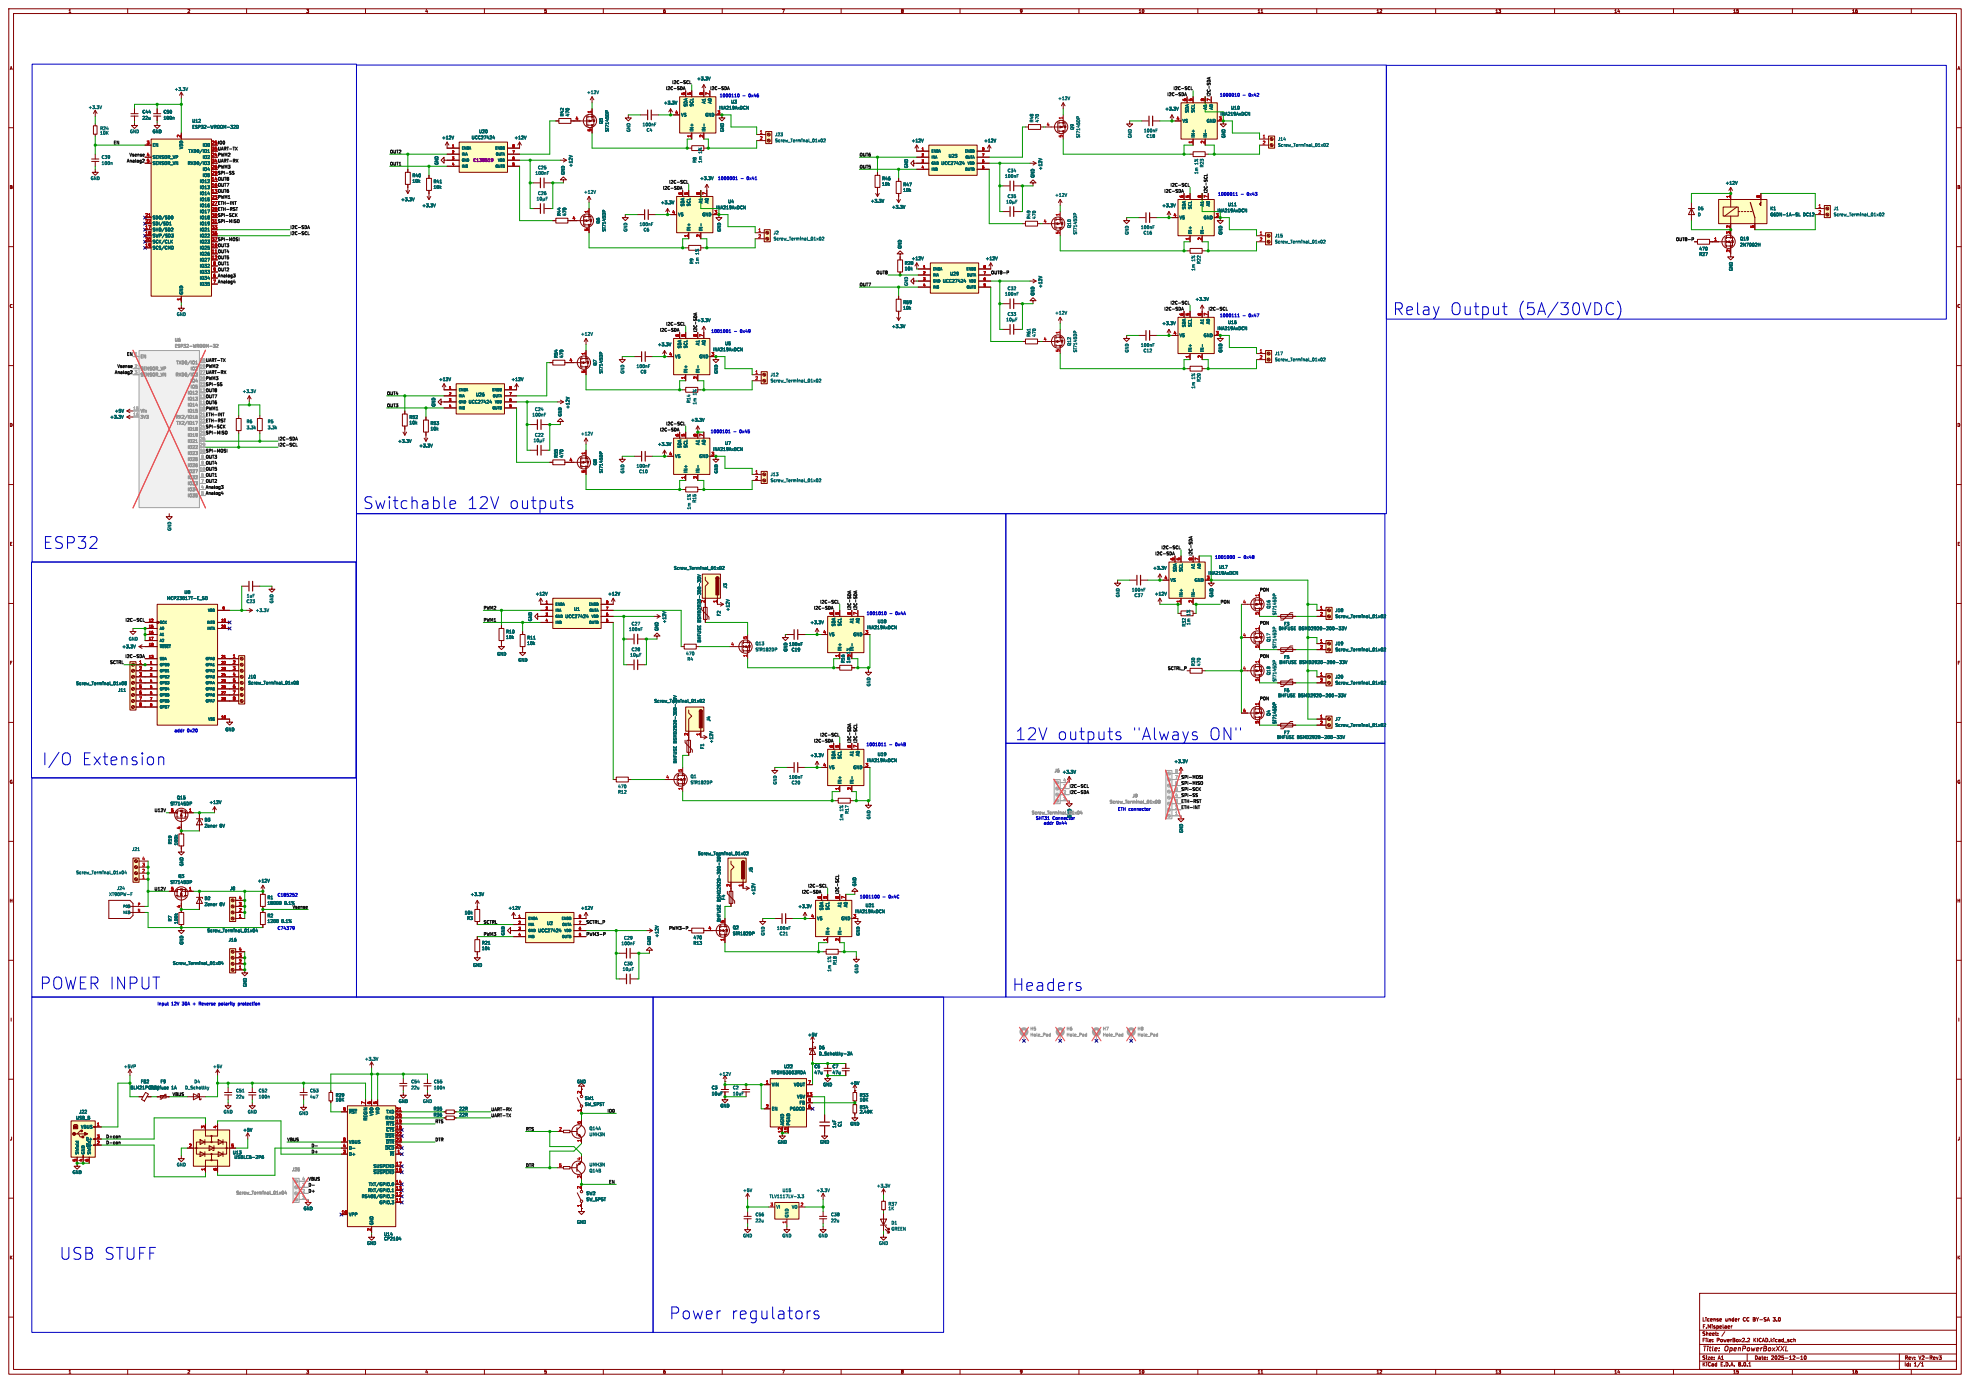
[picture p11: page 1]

1 IN- 2 GND 3 VS 4 SCL
INA219AxDCN IN+

2 SCK/CLK 20 SDO/SD0 21 SDI/SD1 22

SPI-SS OUT6 ETH-INT Analog4 OUT5 Analog3 OUT1 UART-TX OUT2 OUT4 OUT3

1 VO 2 VI 3 U15 TLV1117LV-3.3 GND GND+12V

ETH-RST SPI-MOSI SPI-MISO

OUT8 PWM2 UART-TX OUT7 PWM3 SPI-SS UART-RX

ETH-RST ETH-INT SPI-MISO

7 VBUS 8 ~{RST} 9 GND GND
GND

2 RXD 20 TXD 21 ~{DSR} 22 ~{DTR} 23 ~{DCD} 24 D+ 3 D- 4 VIO

6 U13 USBLC6-2P6 ~{RI}1 GPIO.3 11 RS485/GPIO.2 12 RXT/GPIO.1 13 TXT/GPIO.0 14 ~{SUSPEND}15 VPP 16 SUSPEND 17 ~{CTS} 18 ~{RTS} 19 GND

6 U14 CP2104 ~{RI}1 GPIO.3 11 RS485/GPIO.2 12 RXT/GPIO.1 13 TXT/GPIO.0 14 ~{SUSPEND}15 VPP 16 SUSPEND 17 ~{CTS} 18 ~{RTS} 19 GND

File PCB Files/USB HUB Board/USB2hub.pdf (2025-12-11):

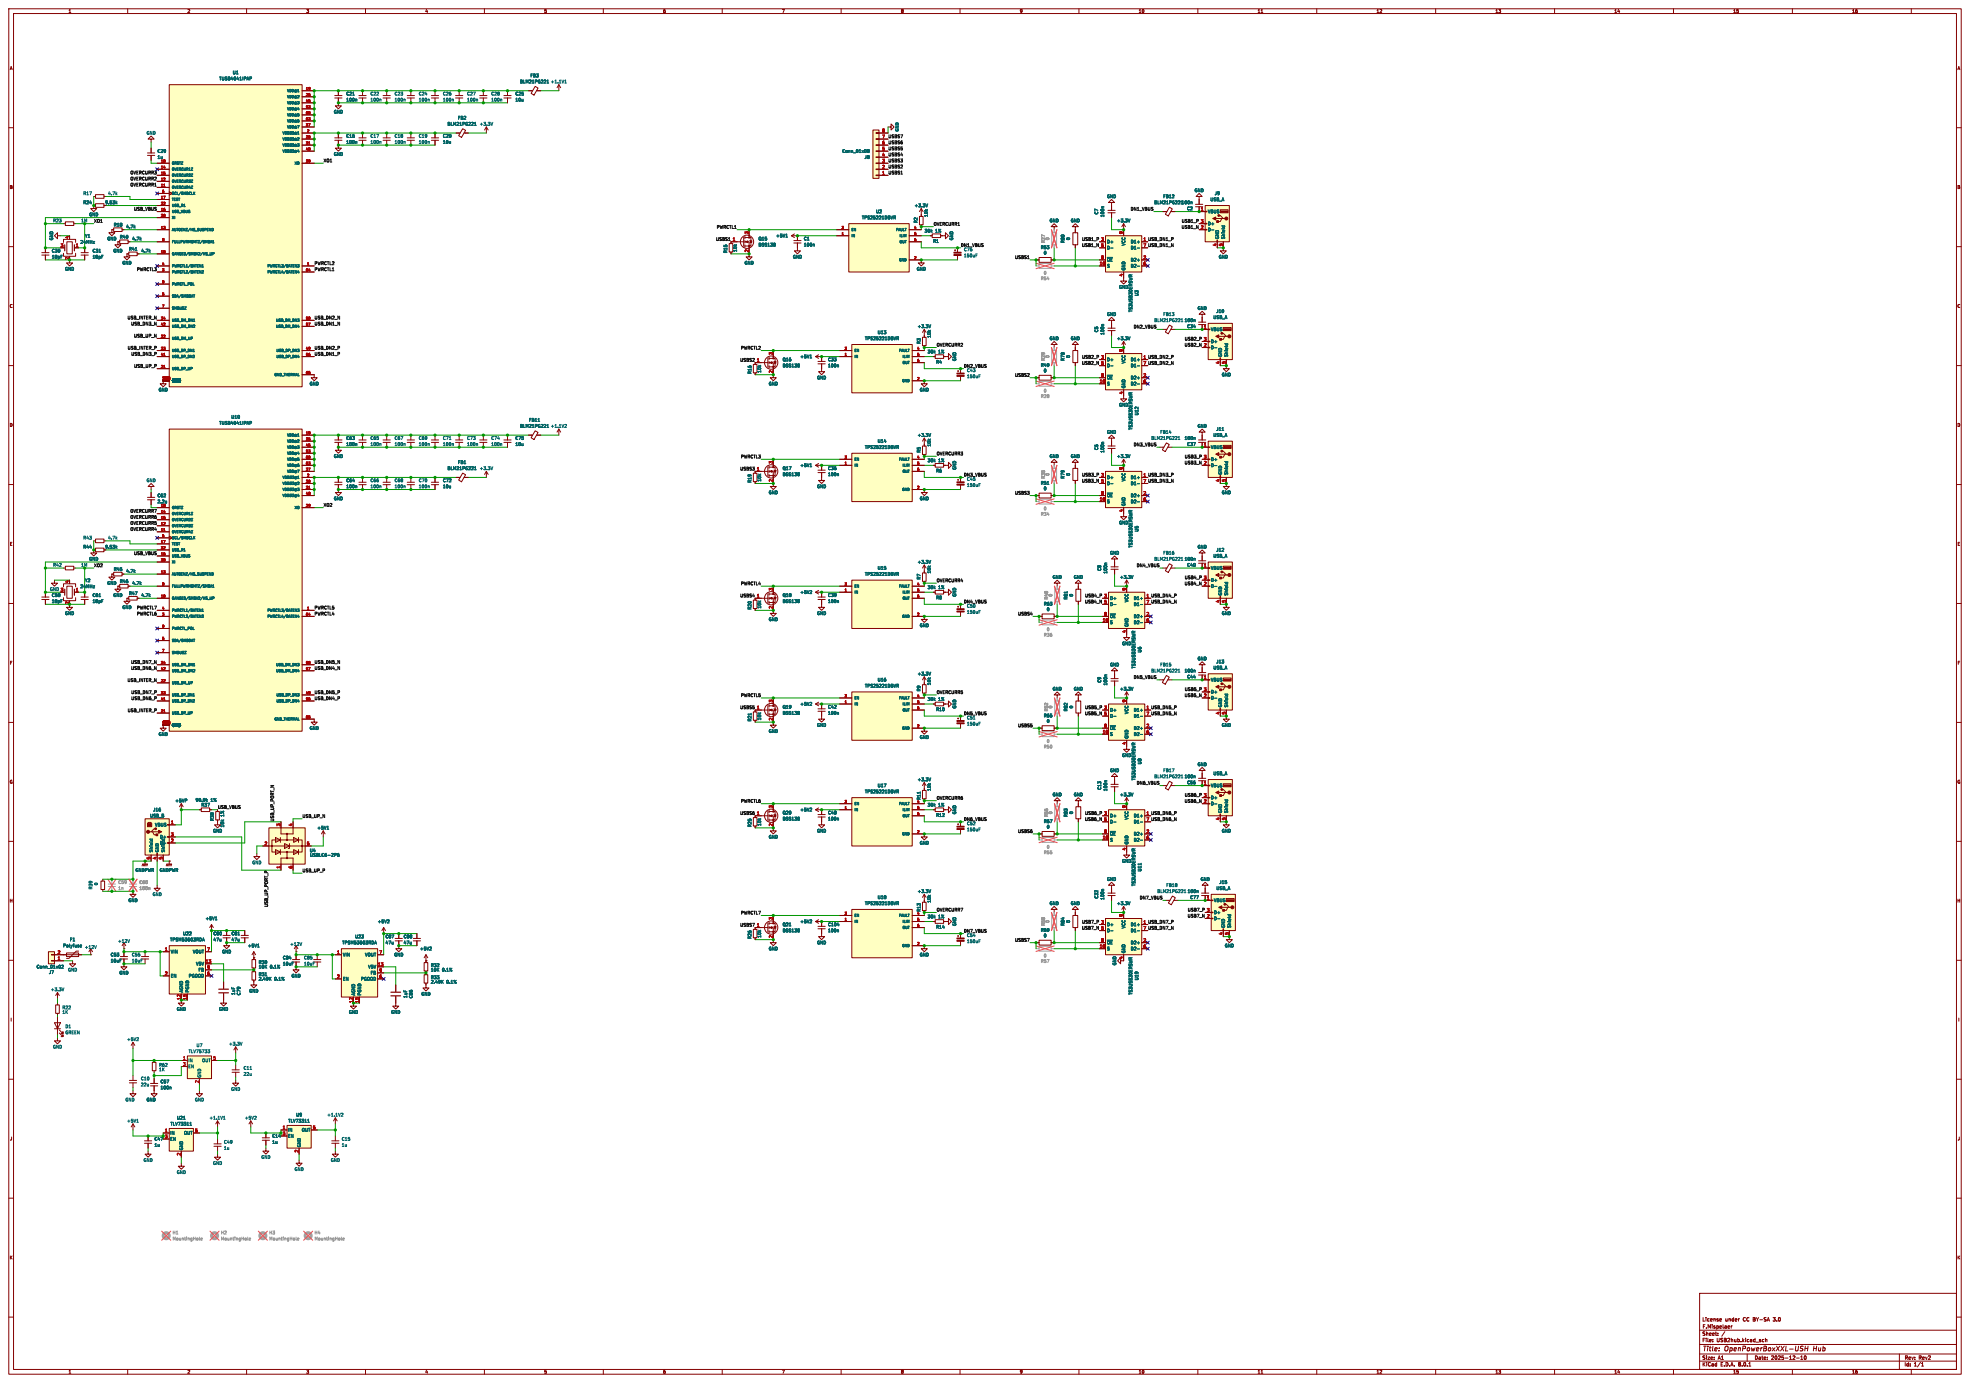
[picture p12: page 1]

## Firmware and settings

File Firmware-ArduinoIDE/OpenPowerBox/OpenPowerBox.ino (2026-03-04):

#include <Arduino.h>
#include "config.h"
#include "SwitchClass.h"
#include <SerialCommand.h>
#include <ErrorManager.h>
#include <Adafruit_MCP23X17.h>
#include "Definitions.h"
#include <WiFi.h>
#include <WiFiUdp.h>
#include <WebServer.h>
#include <WebSocketsServer.h>
#include <ArduinoJson.h>
#include <EEPROM.h>
#include "EEPROMManager.h"


Switch _switch;

// Server declarations
WebServer *_ascomserver;                           // ASCOM server used for the ASCOM/ALAPCA client interface
WebSocketsServer webSocket = WebSocketsServer(81); // the websocket uses port 81 (standard port for websockets)
WiFiUDP _ASCOMDISCOVERYUdp;                        // UDP server for ASCOM discovery protocol. An Alpaca driver setup dialogue will probe the local network through UDP in order to find every devices that uses the ALPACA API.

int total;
int auto_out = 0;
int sensetimer, sensetimer2;
bool measureflag = 0;

bool UIChanged = false;

SerialCommand sCmd; // The demo SerialCommand object

double timesincelastupdate = 0;
int interval = 1000;              // send data to the client every 1000ms -> 1s
unsigned long previousMillis = 0; // we use the "millis()" command for time reference and this will output an unsigned long

// functions declaration for PLATFORMIO.
// Comment out this section if building in Arduino IDE
bool errortest(int, int);

void currentLimiter();

void processCommand();

void UpdateWebpageReadings();
void UpdatewifiParam();
void UpdateNameParam();
void UpdateLimitParam();
void UpdatePolarityParam();
void webSocketEvent(byte, WStype_t, uint8_t *, size_t);
void checkASCOMALPACADiscovery();
void getURLParameters();
int getURLindex();

void get_setup();
void get_man_version();
void get_man_description();
void get_man_configureddevices();
void get_description();
void get_name();
void get_driverinfo();
void get_driverversion();
void set_connected();
void set_connect();
void set_disconnect();
void get_connected();
void get_connecting();
String addclientinfo(String);
void get_supportedactions();
void sendreply(int, String, String);
void get_switch();
void set_switch();
void get_switchvalue();
void set_switchvalue();
void get_maxswitch();
void get_canwrite();
void get_switchdescription();
void get_switchname();
void get_minswitchvalue();
void get_maxswitchvalue();
void get_switchstep();
void set_averageperiod();
void get_notfound();
void get_interfaceversion();
void get_async();
void set_async();
void set_cancelasync();
void get_statechangecomplete();
//================================================

//===========================================================================
//===================== MAIN MICROCONTROLLER FUNCTIONS ======================
//===========================================================================

void setup()
{

  // Initializing the Serial port
  Serial.begin(115200);
  delay(2000);
  EEPROM.begin(EEPROM_SIZE);
  _switch = Switch(0);
  // Initializing the ascom server
  _ascomserver = new WebServer(4040);

  //Initializing WIFI-------------
    //ssid1=""; 
    //pwd1=""; 

  WiFi.begin(ssid1, pwd1);                                               // start WiFi interface
  Serial.println("Establishing connection to WiFi with SSID: " + ssid1); // print SSID to the serial interface for debugging
  Serial.println(WiFi.macAddress());
  
int x=0;
  while (WiFi.status() != WL_CONNECTED)
  { // wait until WiFi is connected
    delay(500);
    Serial.print(".");
    if(x>10) 
    {
      Serial.println("Failed to connect to wifi. Moving on");
      break;
    }
    x++;
  }

  Serial.print("Connected to network with IP address: ");
  Serial.println("#i0:" + WiFi.localIP().toString() + ";");
  // WIFI-------------

  if(WiFi.status() == WL_CONNECTED){
  // Initializing the ASCOM UDP server
  _ASCOMDISCOVERYUdp.begin(ASCOMDISCOVERYPORT);

  // Implementing the ALPACA API for a switch device.
  // Reference specifications : https://ascom-standards.org/api/#/ASCOM%20Methods%20Common%20To%20All%20Devices

  _ascomserver->on("/", get_setup);
  _ascomserver->on("/setup", get_setup);

  // // handle Management requests

  _ascomserver->on("/management/apiversions", get_man_version);
  _ascomserver->on("/management/v1/description", get_man_description);
  _ascomserver->on("/management/v1/configureddevices", get_man_configureddevices);

  // // handle ASCOM driver client requests

  _ascomserver->on("/api/v1/switch/0/connecting", HTTP_GET, get_connecting);
  _ascomserver->on("/api/v1/switch/0/connected", HTTP_GET, get_connected);
  _ascomserver->on("/api/v1/switch/0/connected", HTTP_PUT, set_connected);
  _ascomserver->on("/api/v1/switch/0/connect", HTTP_PUT, set_connect);
  _ascomserver->on("/api/v1/switch/0/disconnect", HTTP_PUT, set_disconnect);
  _ascomserver->on("/api/v1/switch/0/canasync", HTTP_GET, get_async);
  _ascomserver->on("/api/v1/switch/0/setasync", HTTP_PUT, set_async);
  _ascomserver->on("/api/v1/switch/0/setasyncvalue", HTTP_PUT, set_async);
  _ascomserver->on("/api/v1/switch/0/cancelasync", HTTP_PUT, set_cancelasync);
  _ascomserver->on("/api/v1/switch/0/canwrite", HTTP_GET, get_canwrite);
  _ascomserver->on("/api/v1/switch/0/statechangecomplete", HTTP_GET, get_statechangecomplete);
  _ascomserver->on("/api/v1/switch/0/interfaceversion", HTTP_GET, get_interfaceversion);
  _ascomserver->on("/api/v1/switch/0/name", HTTP_GET, get_name);
  _ascomserver->on("/api/v1/switch/0/description", HTTP_GET, get_description);
  _ascomserver->on("/api/v1/switch/0/driverinfo", HTTP_GET, get_driverinfo);
  _ascomserver->on("/api/v1/switch/0/driverversion", HTTP_GET, get_driverversion);
  _ascomserver->on("/api/v1/switch/0/getswitch", HTTP_GET, get_switch);
  _ascomserver->on("/api/v1/switch/0/getswitchvalue", HTTP_GET, get_switchvalue);
  _ascomserver->on("/api/v1/switch/0/setswitch", HTTP_PUT, set_switch);
  _ascomserver->on("/api/v1/switch/0/setswitchvalue", HTTP_PUT, set_switchvalue);
  _ascomserver->on("/api/v1/switch/0/maxswitch", HTTP_GET, get_maxswitch);
  _ascomserver->on("/api/v1/switch/0/getswitchdescription", HTTP_GET, get_switchdescription);
  _ascomserver->on("/api/v1/switch/0/getswitchname", HTTP_GET, get_switchname);
  //_ascomserver->on("/api/v1/switch/0/setswitchname", HTTP_PUT, set_switchname);
  _ascomserver->on("/api/v1/switch/0/minswitchvalue", HTTP_GET, get_minswitchvalue);
  _ascomserver->on("/api/v1/switch/0/maxswitchvalue", HTTP_GET, get_maxswitchvalue);
  _ascomserver->on("/api/v1/switch/0/switchstep", HTTP_GET, get_switchstep);
  _ascomserver->on("/api/v1/switch/0/supportedactions", HTTP_GET, get_supportedactions);



  // // handle url not found 404

  _ascomserver->onNotFound(get_notfound);
  _ascomserver->begin();
  webSocket.begin();                 // start websocket
  webSocket.onEvent(webSocketEvent); // define a callback function -> what does the ESP32 need to do when an event from the websocket is received? -> run function "webSocketEvent()"
  }
  // Initializing the serial command parser
  sCmd.addCommand("#", processCommand);
  total = _switch.maxswitch();
  sensetimer = millis();
}

void loop()
{
  // Ascom Server execution
  if(WiFi.status() == WL_CONNECTED){
  _ascomserver->handleClient();
  // check for ALPACA discovery received packets
  checkASCOMALPACADiscovery();

  // Update function for the webSockets
  webSocket.loop();

  // Update function that sends the last mean measurtements to the webpage.
    UpdateWebpageReadings();    

  }
  // We restart the board every 48 hours to prevent any memory fragmentation.
  if (millis() > 2 * 24 * 60 * 60 * 1000)
    ESP.restart();

  // Serial bus Receiver handler
  sCmd.readSerial(); // We don't do much, just process serial commands

  if (Ren)
  {
      float delta = _switch.Temperature-_switch.DewPoint();

      for(int i=0;i<PWMOutput_Num;i++)
      {
        if(_switch.getswitchvalue(DCOutput_Num +PWMOutput_Num +i)==1) 
         {
          if(delta<2) _switch.setpwm(i, 100);
          else if ((delta>=2)&&(delta<3)) _switch.setpwm(i, 80);
          else if ((delta>=3)&&(delta<4)) _switch.setpwm(i, 60);
          else if ((delta>=4)&&(delta<5)) _switch.setpwm(i, 40);
          else if ((delta>=5)&&(delta<6)) _switch.setpwm(i, 20);
          else _switch.setpwm(i, 0);
         }
      }
  }

  // Serial bus Transmitter handler
  sensetimer2 = millis() - sensetimer;

  if (sensetimer2 > MeasureInterval)
  {
    _switch.getAllSensors();
    currentLimiter();
    sensetimer = millis();
  }
}


//===========================================================================
//======================= USB/UART MESSAGE HANDLER ==========================
//===========================================================================

// This function is called when a command is received from the Serial port
// It processes the command and sends a response back to the Serial port
// The command format is:
// # <command> <switchNum> <value>
// For example:
// # S 1 1       Set switch 1 to value 1
// # G 4         Get switch 4 value
// if only the switch number is expected, <value> is not needed and if one is still provided, it is ignored.
// if <value> is not provided but expected, an error message is sent back to the Serial port (TO DO).
// The response format is:
// #<command><switchNum>:<value>;
// where <command> is the same as above, <switchNum> is the switch number and <value> is the value of the switch or the response to the command.
// The response is sent back to the Serial port.
// If the command is not recognized, an error message is sent back to the Serial port (TO DO).
// If the command is not valid, an error message is sent back to the Serial port (TO DO).

void processCommand()
{
  char *arg;
  char cmd;
  int i, value;
  String answer,value2;
  arg = sCmd.next();
  if (arg != NULL)
    cmd = arg[0];
  // else Serial.println("No arguments");

  arg = sCmd.next();
  if (arg != NULL)
    i = atoi(arg); // Converts a char string to an integer
  // else Serial.println("No second arguments");

  arg = sCmd.next();
  if (arg != NULL)
     {value = atol(arg);
     value2 = arg;}

  switch (cmd)
  {
  case 'S':
    if (_switch.getswitchvalue(SensorPos) < 10.0) {
    Serial.println(ASCOM_err[9]);//Checking undervoltage
    break;
    }
    UIChanged = true;
    Serial.println("Setting switch " + String(i) + " to value " + String(value));
    _switch.setswitchvalue(i, value);
    Serial.println("#G" + String(i) + ":" + String(_switch.getswitchvalue(i)) + ";");
    break;
  case 'G':
    Serial.println("#G" + String(i) + ":" + String(_switch.getswitchvalue(i)) + ";");
    break;
  case 'N':
    _switch.setswitchname(i, arg);
    Serial.println("#n" + String(i) + ":" + String(_switch.getswitchname(i)) + ";");
    break;
  case 'n':
    Serial.println("#n" + String(i) + ":" + String(_switch.getswitchname(i)) + ";");
    break;
  case 'D':
    Serial.println("#D" + String(i) + ":" + String(_switch.getswitchdescription(i)) + ";");
    break;
  case 'W':
    Serial.println("#W" + String(i) + ":" + String(_switch.canwrite(i)) + ";");
    break;
  case 'm':
    Serial.println("#m" + String(i) + ":" + String(_switch.minswitchvalue(i)) + ";");
    break;
  case 'M':
    Serial.println("#M" + String(i) + ":" + String(_switch.maxswitchvalue(i)) + ";");
    break;
  case 'X':
    Serial.println("#X0:" + String(TotalOutputNum) + ";");
    break;
  case 'Z':
    answer = "#Z0:";
    answer += String(DCOutput_Num) + ",";
    answer += String(PWMOutput_Num) + ",";
    answer += String(RelayOutput_Num) + ",";
    answer += String(OnOutput_Num) + ",";
    answer += String(USBOutput_Num) + ",";
    answer += String((short)Ren) + ";";
    Serial.println(answer);
    break;
  case 'r':
    Serial.println("#r" + String(i) + ":" + String(_switch.getreverse(i)) + ";");
    break;
  case 'R':
    _switch.setreverse(i, value);
    Serial.println("#r" + String(i) + ":" + String(_switch.getreverse(i)) + ";");
    break;
  case 'l':
    Serial.println("#l" + String(i) + ":" + String(_switch.getlimit(i)) + ";");
    break;
  case 'L':
    _switch.setlimit(i, value);
    Serial.println("#l" + String(i) + ":" + String(_switch.getlimit(i)) + ";");
    break;    
  case 'T':
    Serial.println("#T" + String(i) + ":" + String(_switch.getswitchtype(i)) + ";");
    break;
  case 'Y':
  _switch.Visible[i] = value;
    Serial.println("#y" + String(i) + ":" + String(_switch.Visible[i]) + ";");
    break;
    case 'y':
    Serial.println("#y" + String(i) + ":" + String(_switch.Visible[i]) + ";");
    break;
    case 'I':
    Serial.println("#i0:" + WiFi.localIP().toString() + ";");
    break;    
    case 'f':
    Serial.println("#f0:" + ssid1 + ";");
    break; 
    case 'F':
    ssid1=value2;
    StoreString(EEPROM_SSID_ADD, ssid1);
    EEPROM.commit();
    Serial.println("#f0:" + ssid1 + ";");
    break; 
    case 'h':
    Serial.println("#h0:***;");
    break; 
    case 'H':
    pwd1=value2;
    StoreString(EEPROM_PWD_ADD, pwd1);
    EEPROM.commit();   
    Serial.println("#h0:***;");
    break; 
    case 'p':
    EEPROM.commit();  
    delay(100);
    ESP.restart();
    break;
    case 'e':
    Serial.println(SwitchErrorMessage);
    break; 
  default:
    Serial.println("Unknown command received");
    break;
  }
}

//===========================================================================
//============================== ERROR HANDLER ==============================
//===========================================================================

bool errortest(int num, int value)
{
  if (Ren == 0)
  {
    if (num > (DCOutput_Num + PWMOutput_Num))
    {
      ASCOM_err_flag[0]=true;
      SwitchErrorMessage = ASCOM_err[0];
      Serial.println(ASCOM_err[0]);
      return 0;
    }
    else ASCOM_err_flag[0]=false;
  }
  else
  {
    if ((num > (DCOutput_Num + PWMOutput_Num)) && (num != total - 1))
    {
      ASCOM_err_flag[0]=true;
      SwitchErrorMessage = ASCOM_err[0];
      Serial.println(ASCOM_err[0]);
      return 0;
    }
    else ASCOM_err_flag[0]=false;
  }

  if ((value > _switch.maxswitchvalue(num)) || (value < _switch.minswitchvalue(num)))
  {
    SwitchErrorMessage = ASCOM_err[1];
    Serial.println(ASCOM_err[1]);
    return 0;
  }
  else ASCOM_err_flag[1]=false;
  return 1;
}

//===========================================================================
//============================ CURRENT LILMITER =============================
//===========================================================================
/* This function is used to limit the current flowing through the system
It is called at regular intervals
Its function is to check the current consumption of the system and to turn off the switches if the current exceeds a certain limit.
Two mode of limiter are engaged at the same time:
  1. The first mode is to turn off a particular switch if the current exceeds its given limit
  2. The second mode is to turn off certain switches in a priority order if the total current exceeds a certain limit.
  The priority order is as follows:
  1. DC Rail bank : 5A whole bank
  2. PWM switches : 3A each
  3. DC switches : 6A each
  In addition, A limiter is set up for the whole DC bank and one for the whole PWM bank.
  The DC bank limiter is set to 10A and the PWM bank limiter is set to 6A.
  The general limiter is set to 25A.
  Those limits are set in the config.h file but it is higly recommended to not change them.
  We would like to remember you that this device is a DIY project and may or may not be safe.
  We decline responsibility for any damage caused by the malfunction of this firmware.*/

void currentLimiter()
{
  int i = 0;
  int j = 0;
  while (i < DCOutput_Num)
  {
    if (_switch.getswitchvalue(sensorDC0 + i * 2 + 1) > _switch.DClimit)
    {
      _switch.setswitchvalue(i, 0);
      _switch.DClimitflag[i] = true;
      Serial.println(ASCOM_err[3] + " DC Output " + String(i) + " Current :" + String(_switch.getswitchvalue(sensorDC0 + i * 2 + 1)) + " Limit :" + String(_switch.DClimit));
    }
    else
      _switch.DClimitflag[i] = false;
    i++;
  }

    while (i < DCOutput_Num + PWMOutput_Num)
  {
    if (_switch.getswitchvalue(sensorPWM0 + j * 2 + 1) > _switch.PWMlimit)
    {
      _switch.setswitchvalue(i, 0);
      _switch.PWMlimitflag[j] = true;
      Serial.println(ASCOM_err[5] + " PWM Output " + String(i));
    }
    else
      _switch.PWMlimitflag[j] = false;
    i++;
    j++;
  }

  i++;
  if (_switch.getswitchvalue(sensorOn0 + 1) > _switch.Onlimit)
  {
    _switch.setswitchvalue(i, 0);
    _switch.Onlimitflag = true;
    Serial.println(ASCOM_err[4] + " On Output " + String(i));
  }
  else
    _switch.Onlimitflag = false;
  i++;


  // Check the total current consumption of the system
  if (_switch.TotalCurrentDC > _switch.TotalDClimit)
  {
      ASCOM_err_flag[6]=true;
      SwitchErrorMessage = ASCOM_err[6];
    _switch.TotalDClimitflag = true;
    Serial.println(ASCOM_err[6] + " Total DC current limit exceeded: " + String(_switch.TotalCurrentDC) + "A");
    for (int i = 0; i < DCOutput_Num; i++)
    {
      _switch.setswitchvalue(i, 0);
    }
  }
  else
    _switch.TotalDClimitflag = false;

  if (_switch.TotalCurrentPWM > _switch.TotalPWMlimit)
  {
    _switch.TotalPWMlimitflag = true;
    Serial.println(ASCOM_err[7] + " Total PWM current limit exceeded: " + String(_switch.TotalCurrentPWM ) + "A");
    for (int i = 0; i < PWMOutput_Num; i++)
    {
      _switch.setswitchvalue(DCOutput_Num + i, 0);
    }
  }
  else
    _switch.TotalPWMlimitflag = false;

  if (_switch.TotalCurrent > _switch.Totallimit)
  {
    Serial.println(ASCOM_err[8] + " Total current limit exceeded: " + String(_switch.TotalCurrent) + "A");
    _switch.setswitchvalue(DCOutput_Num+PWMOutput_Num, 0); // Turn off On
      if (_switch.TotalCurrent > _switch.Totallimit)
      {
        Serial.println(ASCOM_err[8] + " Total current limit exceeded: " + String(_switch.TotalCurrent) + "A");
        for (int i = 0; i < PWMOutput_Num; i++)
        {
          _switch.setswitchvalue(DCOutput_Num+i, 0); // Turn off all PWM outputs
          _switch.TotalCurrentflag = true;
        }
      }
    }
  
  else
    _switch.TotalCurrentflag = false;


    //Setting flags for error messages to display in the client
    SwitchErrorMessage="#E0: ;";
    for(int i=0; i<DCOutput_Num;i++) 
    {
      if(_switch.DClimitflag[i]) 
      {
        SwitchErrorMessage= ASCOM_err[3];
        ASCOM_err_flag[3]=true; 
      }
      else ASCOM_err_flag[3]=false;
    }
    
    if(_switch.Onlimitflag) 
    {
     SwitchErrorMessage= ASCOM_err[4];
      ASCOM_err_flag[4]=true; 
    }
    else ASCOM_err_flag[4]=false;

    for(int i=0; i<PWMOutput_Num;i++) 
    {
      if(_switch.PWMlimitflag[i]) 
      {
        SwitchErrorMessage= ASCOM_err[5];
        ASCOM_err_flag[5]=true; 
      }
      else ASCOM_err_flag[5]=false;
    }

    if(_switch.TotalDClimitflag)
    {
      ASCOM_err_flag[6]=true; 
      SwitchErrorMessage= ASCOM_err[6];
    }
    if(_switch.TotalPWMlimitflag)
    {
      ASCOM_err_flag[7]=true; 
      SwitchErrorMessage= ASCOM_err[7];
    }
    if(_switch.TotalCurrentflag)
    {
      ASCOM_err_flag[8]=true; 
      SwitchErrorMessage= ASCOM_err[8];
    }
    if(_switch.InputVoltage<10.0)
  {
    ASCOM_err_flag[9]=true;
    SwitchErrorMessage = ASCOM_err[9];
  }
  else ASCOM_err_flag[9]=false;
}



//===========================================================================
//============================ WEBPAGE FUNCTIONS =============================
//===========================================================================
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

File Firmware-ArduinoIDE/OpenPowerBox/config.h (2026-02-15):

#ifndef _config_h
#define _config_h

#include <Arduino.h>

//===========================================================================
//============================ CONFIGURATION FILE ===========================
// ======== Go over every part in the file to configure your device =========
//===========================================================================

//===========================================================================
//======================== Communication Bus Options ========================
//===========================================================================

/*By default USB and Uart are used as the communication carrier with the client.
Wifi and Ethernet will also be supported in the future.
If you need any of them, uncomment the corresponding enableflag below.
If your hardware supports multiple of them, you can enable more than one.*/

// #define WiFi_enableFlag
// #define Ethernet_enableFlag

//===========================================================================
//=================== Number of outputs and sensors Options =================
//===========================================================================

/*Self explanatory. Define here the number of 12V outputs, the number of PWM outputs and the number of ina219 current sensors.
Be aware of the maximum for each one. If you specify more, the firmware will ignore those entries and use the maximum allowed*/

const short DCOutput_Num = 7;  // Number of stable 12V outputs. 
const short PWMOutput_Num = 3; // Number of PWM controlled outputs.
const short RelayOutput_Num = 1; // Number of relay outputs.
const short OnOutput_Num = 1; // Number of always ON 12V switches (the whole bank of connectors is controlled by the same switch)
const short USBOutput_Num = 7; // Number of USB controlled outputs. Maximum is 7.
const bool Ren =true; // Falg to enable/disable the automatic power control of dew heaters. This only affects the firmware and display of the sensor, you will still have to activate automatic control in the driver.
 

const short Sensor_Num = DCOutput_Num + OnOutput_Num + PWMOutput_Num; 
const short TotalOutputNum = DCOutput_Num + RelayOutput_Num + OnOutput_Num + 2*PWMOutput_Num + USBOutput_Num + 2 * Sensor_Num +4+3*(short)Ren ;
const int totalswitches= DCOutput_Num + 2*PWMOutput_Num  + RelayOutput_Num + OnOutput_Num+USBOutput_Num;

const int SensorPos= DCOutput_Num + 2*PWMOutput_Num + RelayOutput_Num + OnOutput_Num + USBOutput_Num; // Position of the first sensor in the switch array
const int sensorDC0 = SensorPos+4; // add 4 to ignore the input voltage and total currents
const int sensorPWM0 = sensorDC0 + DCOutput_Num * 2;
const int sensorOn0 = sensorPWM0 + PWMOutput_Num * 2;
const int sensorRen0 = sensorOn0 + OnOutput_Num * 2;
//===========================================================================
//============================= Pin configguration ==========================
//===========================================================================

/*Specify the pin numbers of Stable outputs or leave default value.
N.B.: the firmware will ignore the outputs past <StableOutput_Num>. For exemple, if StableOutput_Num=3, check the first 3 outputs and number 4 to 10 will be ignored.
You only need to check the outputs from n°1 to <StableOutput_Num>.

N.B2: There may be not enough pins on the esp32. This firmware has an option to use the GPIO expander MCP23017 in order to add more control pins.
To identify them, replace the normal pinnumber with 10x, depending on the number of the I/O on the chip.
The firmware will automatically recognise the extra number as being an I/O of the expander. By default the last two on the list below ar A0 and A1.*/

/*Pin Name 	Pin ID
GPA0 	0 -> 100
GPA1 	1 -> 101
GPA2 	2 -> 102
GPA3 	3 -> 103
GPA4 	4 -> 104
GPA5 	5 -> 105
GPA6 	6 -> 106
GPA7 	7 -> 107
GPB0 	8 -> 108
GPB1 	9 -> 109
GPB2 	10 -> 110
GPB3 	11 -> 111
GPB4 	12 -> 112
GPB5 	13 -> 113
GPB6 	14 -> 114
GPB7 	15 -> 115
*/

const short DCOutput_Pin[DCOutput_Num] =
    {
        32,
        33,
        25,
        26,
        27,
        14,
        13,
};
const short RelayOutput_Pin = 12;
const short OnOutput_Pin = 108;

/*Specify the pin numbers of PWM outputs or leave default value.
N.B.: the firmware will ignore the outputs past <PWMOutput_Num>. For exemple, if PWMOutput_Num=1, check the first output and number 2 to 3 will be ignored.
You only need to check the outputs from n°1 to <PWMOutput_Num>. */
const short PWMOutput_Pin[PWMOutput_Num] =
    {
        15,
        2,
        4};

const short USBOutput_Pin[13] =
    {
        100,
        101,
        102,
        103,
        104,
        105,
        106,
};        

/*Configure the logic of your power transistors.
Reverse = 0, Output is ON when Signal is ON
Reverse = 1, Output is ON when Signal is OFF
*/
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

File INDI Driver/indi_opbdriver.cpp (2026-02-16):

/*******************************************************************************
 * INDI Driver for the project Open Power Box
 *
 * Copyright (C) 2026 Mispelaer Florent 
 *
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
 * DESCRIPTION 
 * 
 * The project (software and hardware)  is available at www.github.com/Antiath/Open-Power-XXL
 * 
 * The Open Power Box is a hardware and software project aiming to provide a versatile and customizable power distribution solution for amateur astronomers. 
 * The device offers multiple 12V outputs, dew hearter outputs all controllable.
 * The hardware side of the project is fixed to 7 DC outputs, 3 dew heater outputs, 1 DC bank output (multiple gagned connectors for devices that dont require individual control), 1 relay output.
 * The hadware comes in two versions, The one descibres just above and a similar one with 7 USB2 switchable ports.
 * The project is primarily designed for large setups wwith multiple instruments ,so typically for observatory setups,
 * but the firmare is configurable to allow developpers to change those numbers at will. The driver will automatically scale itself according to those parameters.
 *  
 * FEATURES
 * - Control of all outputs (DC, Dew, USB) with individual ON/OFF commands, as well as duty cycle control for dew heaters.
 * - Tutomatic control mode for dew heaters.
 * - Real-time monitoring of voltage, current and power consumption for each DC ouputs and Dew outpouts, as well as total consumption.
 * - Hardware fuses are provided for the dew heaters but not for the DC Outputs ( to avoid unwanted voltage drops that can mess with some devices like QHY cameras).
 * - Software fuses (current limits) on all outputs, configrurable in the driver.
 * - Reboot command to reset the device.
 * - WiFi connectivity settings of the web browser interface (at http://IP_ADDRESS/4040). Driver only uses USB though.
 * - Configurable output names that can be set from the driver and are stored in the device's memory.
 * - Polarity (switch polarity , not voltage polarity) inversion for all outputs.
 * - Web browser interface handled by the device.
 * 
 ******************************************************************************/

#include "indi_opbdriver.h"

#include <memory>

#include <algorithm>
#include <cmath>
#include <cstring>
#include <fcntl.h>
#include <memory>
#include <sstream>
#include <sys/ioctl.h>
#include <termios.h>
#include <unistd.h>
#include <iostream>

std::unique_ptr<OPB> opb(new OPB());

OPB::OPB() : INDI::DefaultDevice(), INDI::PowerInterface(this)
{
    setVersion(1, 0);
    initialized=false;
}


const char *OPB::getDefaultName()
{
    return "Open Power Box";
}


///////////////////////////////////////////////////////////////////////
/// Initialization of properties that don't need pior connection to the device.
/// Remark : The driver has no knowledge of the number of ports. 
/// It wil fetch this information from the device after connection, and then initialize the properties accordingly. 
//////////////////////////////////////////////////////////////////////

bool OPB::initProperties() 
{
    INDI::DefaultDevice::initProperties();
    
        // Reboot
    RebootSP[0].fill("REBOOT", "Reboot Device", ISS_OFF);
    RebootSP.fill(getDefaultName(), "REBOOT_DEVICE", "Device", MAIN_CONTROL_TAB, IP_RW, ISR_ATMOST1,60, IPS_IDLE);
    
        // Connection port
    PortTP[0].fill("PORT", "Port", "/dev/serial/by-id/usb-Silicon_Labs_CP2104_USB_to_UART_Bridge_Controller_02D7B25D-if00-port0");
    PortTP.fill(getDeviceName(), "DEVICE_PORT", "Connection", CONNECTION_TAB, IP_RW, 60, IPS_IDLE);


        // WiFi settings    
    WifiTP[0].fill("IP_ADRESS", "IP Adress", "-");
    WifiTP[1].fill("SSID", "WiFi SSID", "-");
    WifiTP[2].fill("PWD", "WiFi Password", "-");
    WifiTP.fill(getDeviceName(), "WIFI", "WiFi", CONNECTION_TAB, IP_RW, 60, IPS_IDLE);
        // Get WiFi info button   
    GetWiFiInfoSP[0].fill("GETWIFIINFO", "Get SSID + IP", ISS_OFF);
    GetWiFiInfoSP.fill(getDefaultName(), "WIFI_INFO", "Wifi info", CONNECTION_TAB, IP_RW, ISR_ATMOST1,60, IPS_IDLE);
    
        // Overall Power Consumption (Custom properties, not part of INDI::Power Interface)
    TotalConsumptionNP[INPUT_VOLTAGE].fill("INPUT_VOLTAGE", "Input Voltage (V)", "%4.2f", 0, 999, 100, 0);
    TotalConsumptionNP[TOTAL_CURRENT].fill("TOTAL_CURRENT", "Total Current (A)", "%4.2f", 0, 999, 100, 0);
    TotalConsumptionNP[TOTAL_POWER].fill("TOTAL_POWER", "Total Power (W)", "%4.2f", 0, 999, 100, 0);
    TotalConsumptionNP.fill(getDeviceName(), "POWER_CONSUMPTION", "Consumption",
                            MAIN_CONTROL_TAB, IP_RO, 60, IPS_IDLE);
    
        // Buttons to toggle all DC outputs and all Dew Heaters in one click
    AllDCSP[0].fill("ALL_DC_ON", "ON", ISS_ON);
    AllDCSP[1].fill("ALL_DC_OFF", "OFF", ISS_OFF);
    AllDCSP.fill(getDeviceName(), "MAIN_DC", "Toggle All DC switches", MAIN_CONTROL_TAB, IP_RW, ISR_1OFMANY, 60, IPS_IDLE);
    defineProperty(AllDCSP);
    
    AllPWMSP[0].fill("ALL_PWM_ON", "ON", ISS_ON);
    AllPWMSP[1].fill("ALL_PWM_OFF", "OFF", ISS_OFF);
    AllPWMSP.fill(getDeviceName(), "MAIN_PWM", "Toggle All Dew Heaters", MAIN_CONTROL_TAB, IP_RW, ISR_1OFMANY, 60, IPS_IDLE);
    defineProperty(AllPWMSP);
    
    Alldc=true;
    Allpwm=true;
    
    setDriverInterface(POWER_INTERFACE);
    
    SetCapability(POWER_HAS_DC_OUT | POWER_HAS_DEW_OUT | POWER_HAS_AUTO_DEW | POWER_HAS_USB_TOGGLE | POWER_HAS_VOLTAGE_SENSOR | POWER_HAS_OVERALL_CURRENT | POWER_HAS_PER_PORT_CURRENT);
    
        // Define port property (needed before connection)
    defineProperty(PortTP);
    defineProperty(WifiTP);

    return true;
}

///////////////////////////////////////////////////////////////////////
/// Update properties after connection to the device or disconnection.
//////////////////////////////////////////////////////////////////////

bool OPB::updateProperties()
{
    INDI::DefaultDevice::updateProperties();
    if (connectedstate)
    {
        defineProperty(RebootSP);
        defineProperty(GetWiFiInfoSP);
        defineProperty(TotalConsumptionNP);
        defineProperty(AllDCSP);
        defineProperty(AllPWMSP);
        PI::updateProperties();
        SetTimer(getCurrentPollingPeriod());
    }
    else
    {
        deleteProperty(GetWiFiInfoSP);
        deleteProperty(RebootSP);
        deleteProperty(AllDCSP);
        deleteProperty(AllPWMSP);
        deleteProperty(TotalConsumptionNP);
        PI::updateProperties();
    }

    return true;
}

bool OPB::Handshake()
{
return true;
}


//////////////////////////////////////////////////////////////////////
/// Handle incoming switch changes from the client and send the corresponding commands to the device.
//////////////////////////////////////////////////////////////////////
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

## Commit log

2025-12-14 Bug Fixes
    - IP get method was not filtering the received bytes and let other messages show up in the IP text box. Corrected
    - Corrected Error get method
2026-02-07 Added Source code of the INDI Driver
2026-02-07 Updated licensing + INDI Driver instructions
    Revise project licensing information and adding build instructions for the INDI driver
2026-02-08 Bug fix for USB management
    Fixed a bug where the indexes of the sensors were not taking into account the the existence of USB switches inside Timerhit.
    Added some comments in the TimerHit routine.
    [indi_opbdriver.cpp]
2026-02-10 Update dew heater control support description
    Simplified the description of dew heater control support.
2026-02-10 Revise build instructions in README.md
    Updated instructions for building the INDI driver.
2026-02-10 Update USB polarity label in ReverseUSBSP
    [indi_opbdriver.cpp]
2026-02-10 Revise INDI driver build instructions in README
    Updated installation instructions for building the INDI driver, including dependency installation and command sequence.
2026-02-13 Changing the i2c address of the DC2 sensor
    Changing the i2c address of the DC2 sensor to 0x46 (previously 0x44) to make room for a SHT31 sensor
    Correcting minor mistakes of the copper pour.
    [BOM-PowerBox2.2 KICAD.csv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]
2026-02-13 Ypdating the address of DC2 sensor
2026-02-15 Enhance README with dew heater control and updates
    Added automatic dew heater control feature and updated table headers for USB HUB version.
2026-02-21 Modified cases for new env. sensor
    [Gland_PG7_M12.f3d, Gland_PG7_M12.step, OPB_enclosure.f3d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]
2026-02-22 Enhance firmware flashing instructions in README
    Added detailed instructions for flashing firmware using PlatformIO and Arduino IDE, including library dependencies and configuration options.
2026-02-22 Added Firmware configfured for the Arduino IDE
2026-02-23 Bug fix + Renaming
    Fixed a bug with the GUI where hitting Restart after having hit Save sent an empty password to the device.
2026-03-04 Bug Fixes
    Code related to the names of the switches was not indexing them properly and failed to load the new names in the EEPROM.
    [Definitions.cpp, OpenPowerBox.ino, SwitchClass.cpp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]
2026-03-25 Update README with USB hub wiring
    Added details about the USB hub wiring
